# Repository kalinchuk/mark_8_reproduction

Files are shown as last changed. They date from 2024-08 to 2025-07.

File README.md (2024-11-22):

# Mark-8 Minicomputer Reproduction

This repository contains schematics, PCBs, instructions and parts lists for the Mark-8 minicomputer reproduction build which can be found at [https://www.youtube.com/watch?v=wndWWRKyKPk](https://www.youtube.com/watch?v=wndWWRKyKPk). The instructions and parts for most of the boards can be found at [https://bytecollector.com/archive/mark_8/My_Mark-8_Info/Mark-8_Construction/RE_Mark-8_Const-NEW.pdf](https://bytecollector.com/archive/mark_8/My_Mark-8_Info/Mark-8_Construction/RE_Mark-8_Const-NEW.pdf)

You can find the transcript of the interview with Jon Titus [here](/jon_titus_interview.txt).

## PCBs

Original Mark-8 PCBs are very rare. Therefore, if one has the desire to build a Mark-8, they need to use reproduction PCBs. I created reproduction PCBs from the layouts found in the construction manual and got a fabricater to fabricate a large quantity of them at a discount. If you're interested in a set, check out the [listing on www.kalinchuk.com](https://www.kalinchuk.com/product-page/mark-8-minicomputer-reproduction-pcb-set).

Mark-8 Reproduction PCBs

You can also fabricate the PCBs yourself by using the Gerber files under the [gerbers](/gerbers) directory.

## Note on Parts

- Any 74XX IC can be substituted with a 54XX (military grade) or, potentially, with a 74LSXX (Low-power Schottky).
- The Molex connectors that I used are the following:
  * 11-pin: https://www.mouser.com/ProductDetail/Molex/09-48-1114?qs=cSZs%252ByTnFTTJe86rNzFWuA%3D%3D
  * 10-pin: https://www.mouser.com/ProductDetail/Molex/09-48-1104?qs=DcEdecHHM4iSJPtLNet8eg%3D%3D
  * 8-pin: https://www.lvelectronics.com/details/item?itemid=MOLEX%2009-52-3081#
  * 6-pin: https://www.mouser.com/ProductDetail/Molex/09-48-1064?qs=qDyi%252BDzW2VMso3J1Nf5Bpg%3D%3D
  * 5-pin: https://www.mouser.com/ProductDetail/Molex/09-48-1054?qs=naUSJSqnqcLTt2tOKFjpcA%3D%3D
  * 2-pin: https://www.mouser.com/ProductDetail/Molex/09-48-1024?qs=SeTnVz%252B%252BFGB4BpEsDXmhhw%3D%3D
  * 1-pin: TBD

## LED Register Display Board

The LED Register Display board is used for displaying the address and contents of memory and output ports. It consists of 32 LEDs (8 for the high address, 8 for the low address, 8 for the address data and 8 for the output data).

### Parts List

| Part | Spec | Part # |
| --- | --- | --- |
| C1 | 100 uF | Sprague TE1211 |
| C2-C4 | 0.1 uF | ST/CO .1uf 25V ceramic disc |
| D1-D32 | 40mA LED | Western Electric LED; Original used Monsanto MV-50 but are very rare |
| R1-R32 | 220 ohm; 1/4W | Any carbon composition resistor |
| IC1-IC6 | 7404 | 5404J |
| IC7-IC8 | 7475 | 7475J |
| IC9 | 7442 | 7442J |
| IC10 | 7402 | 7402J |
| P1 | 3.96mm 8-pin| Molex 09-52-3081 |
| 41-PIN | 3.96mm 41-pin | MOLEX 09-48-1104 (x3) MOLEX 09-48-1114 (x1) |

### PCB

Mark-8 LED Register Display Board

## Output Ports Board

The output board is used for outputting data from the computer. It's a fairly simple board mostly consisting of ICs.

### Jumpers

There is one jumper in the middle of the board that needs to be installed. The additional jumpers will need to be installed according to the needs. For example, "A" can be jumpered with "1" to make CPU port 1 be output port A on the specific board. This allows for a maximum of 7 output ports with two output port boards.

Output Ports Jumpers

### Parts List

| Part | Spec | Part # |
| --- | --- | --- |
| C1-C3 | 0.1 uF | ST/CO .1uf 25V ceramic disc |
| IC1-IC8 | 7475 | 7475J |
| IC9-IC10 | 7404 | 7404J |
| IC11 | 7402 | 7402J |
| IC12 | 7442 | 7442J |
| P1-P4 | 3.96mm 8-pin| Molex 09-52-3081 |
| 41-PIN | 3.96mm 41-pin | MOLEX 09-48-1104 (x3) MOLEX 09-48-1114 (x1) |

### Test Circuit

The test circuit was taken from the Mark-8 Construction Manual Experiments section.

Output Ports Board Test Circuit

The following code will output 10101010 to output port 1 (remember that output port 0 is on the LED register display).

```
LDAI    AA       ;006 252
OUT1             ;123
HLT              ;777
```

### PCB

Output Ports Board

## Memory Board

The memory board accepts 32-1101 SRAM ICs but requires a minimum of 8 of them. Multiple memory boards can be installed into the Mark-8 computer and linked together.

### Bugs

Ensure that the 8 holes at the top of the board (going to the top connector) are not connected to GND with vias. Early versions of the reproduction PCBs will require those 8 holes to be drilled out.

### Jumpers

There is one jumper between IC33 and IC34. If this memory board is the first (and only) memory board to be installed, jumper the "0" position and the "A" positions. Additionally, select the correct memory block with the jumper positions above IC33. First memory board needs to jumper "0" to "A", "1" to "B", "2" to "C" and "3" to "D". If installing additional memory boards into the Mark-8, the jumpers would be different. Refer to page 6 of the Mark-8 construction manual for more details.

Memory Board Jumpers

### Parts List

| Part | Spec | Part # |
| --- | --- | --- |
| C1-C3 | 0.1 uF | ST/CO .1uf 25V ceramic disc |
| IC1-IC8 | 1101A or 1101A1 | 1101A |
| IC9-IC32 | 1101A or 1101A1 | *Optional |
| IC33 | 7442 | 7442J |
| IC34 | 7400 | 5400J |
| *R1-R11, R20-R21 | 1k ohm; 1/4W | Any carbon composition resistor |
| *R12-R19 | 10k ohm; 1/4W | Any carbon composition resistor |
| P1 | 3.96mm 8-pin| Molex 09-52-3081 |
| P2 | 3.96mm 2-pin| Molex 09-48-1024 |
| 41-PIN | 3.96mm 41-pin | MOLEX 09-48-1104 (x3) MOLEX 09-48-1114 (x1) |

* For the first memory board, install all resistors. If installing additional memory boards, some resistors are omitted. Refer to page 6 of the Mark-8 construction manual for more details.

### Test Program

The following code will output 10101010 to output port 0 (LED register display) to test the functionality of the memory board.

```
LDAI    AA       ;006 252
OUT0             ;121
HLT              ;777
```

### PCB

Memory Board

## Address Latch Board

The address latch board latches addresses specified by the end-user which are then relayed to the memory board.

### Bugs

In addition to the bugs specified on the official bugs sheet, IC8-IC11 pin 4 needs to be pulled up to +5v with a 1k ohm pull-resistor (ref: https://www.ti.com/lit/ds/symlink/sn54ls193-sp.pdf).

Address Latch Board Pull-Up Resistors

Early versions of the reproduction PCBs also have an additional bug - one of the vias is missing and needs to be drilled out and connected with a piece of wire.

Address Latch Board Bug

### Jumpers

There are two jumpers that need to be installed. The larger jumper is not annotated on the parts layout sheet but the holes do exist for it.

Address Latch Board Jumpers

### Parts List

| Part | Spec | Part # |
| --- | --- | --- |
| C1-C6 | *0.1 uF | ST/CO .1uf 25V ceramic disc |
| C7 | 680 pF | RMC 680pf 100V ceramic disc |
| IC1-IC2 | 74123 | 74123J |
| IC3-IC7 | 7400 | 5400J |
| IC8-IC11 | 74193 | 74193J |
| R1-R3 | 10k ohm; 1/4W | Any carbon composition resistor |
| R4 | 22k ohm; 1/4W | Any carbon composition resistor |
| R5-R16 | 1k ohm; 1/4W | Any carbon composition resistor |
| P1 | 3.96mm 8-pin| Molex 09-52-3081 |
| P2 | 3.96mm 5-pin| Molex 09-48-1054 |
| P2 | 3.96mm 6-pin| Molex 09-48-1064 |
| 41-PIN | 3.96mm 41-pin | MOLEX 09-48-1104 (x3) MOLEX 09-48-1114 (x1) |

* The original parts list calls for 0.01 uF but that may be a mistake so I decided to use 0.1 uF instead.

### PCB

Address Latch Board

## Input Multiplex Board

The input multiplex board controls all data flowing into the computer and data between memory and CPU.

### Bugs

In addition to the bugs specified on the official bugs sheet, older versions of this board had two fabrication issues.

The jumper on the right side is missing a hole. This is because the other side of the board does not have a pad. This can be fixed by drilling out a hole using a [#60 (1mm) drill bit](https://amzn.to/3Vpg0OW) and [chuck](https://amzn.to/3VcrNii). Alternatively, a jumper wire can be soldered directly onto the trace.

Input Multiplex Board Bug 1

IC1 has one of the pins connected to a passing trace. This is a frabrication issue and can be fixed by cutting the connection with a utility knife or small grinder (carefully).

Input Multiplex Board Bug 2

### Jumpers

There are two official jumpers and one additional jumper which was noted on the bugs sheet.

Input Multiplex Board Jumpers

### Parts List

| Part | Spec | Part # |
| --- | --- | --- |
| C1, C3-C4  | 0.1 uF | ST/CO .1uf 25V ceramic disc |
| C2 | 100 uF | Sprague TE1211 |
| IC1-IC2 | 8263 MUX | N8263N - can be found on eBay |
| IC3 | 7400 | 7400J |
| IC4-IC5 | 8267 MUX | N8267B - can be found on eBay. Do not use 8266 |
| IC6 | 7402 | 7402J |
| IC7 | 7442 | 7442J |
| R1 | 1k ohm; 1/4W | Any carbon composition resistor |
| P1-P4 | 3.96mm 8-pin| Molex 09-52-3081 |
| 41-PIN | 3.96mm 41-pin | MOLEX 09-48-1104 (x3) MOLEX 09-48-1114 (x1) |

### PCB

Input Multiplex Board

## CPU Board

The CPU board contains the 8008 microprocessor and is the "brain" of the computer.

### Bugs

The bugs sheet on page 46 states that IC3 pin 4 can be connected to ground. Some boards may have experienced issues with the pin not being grounded.

### Jumpers

The board has two official jumpers as annotated on the parts layout sheet.

CPU Board Jumpers

As mentioned in the Bugs section, I went ahead and connected IC3 pin 4 to ground by soldering it to the passing trace (since that trace is connected to ground).

CPU Board Bug

### Parts List

| Part | Spec | Part # |
| --- | --- | --- |
| C1 | 33 pF | RMC 3000V 33pF 10% ceramic disc |
| C2-C6 | 0.1 uF | ST/CO .1uf 25V ceramic disc |
| IC1, IC4, IC6-IC7, IC9, IC13, IC17, IC19 | 7400 | 5400J |
| IC2-IC3, IC14 | 7476 | 5476J |
| IC5, IC11, IC16, IC20, IC21 | 7404 | 5404J |
| IC8, IC12 | 7474 | 5474J |
| IC22-IC23, IC25 | 74L04 | 74L04 |
| IC10, IC18 | 7410 | 7410J |
| IC15 | 7420 | 7420J |
| IC24 | Intel 8008 | Intel C8008 |
| IC26 | 7442 | 7442J |
| R1-R2 | 220 ohm; 1/4W | Any carbon composition resistor |
| R3 | 560 ohm; 1/4W | Any carbon composition resistor |
| R4 | 1.8k ohm; 1/4W | Any carbon composition resistor |
| R5-R8, R17 | 1k ohm; 1/4W | Any carbon composition resistor |
| R9-R16 | 22k ohm; 1/4W | Any carbon composition resistor |
| XTAL 1 | 4.0 MHz | 4.0 MHz Crystal |
| 41-PIN | 3.96mm 41-pin | MOLEX 09-48-1104 (x3) MOLEX 09-48-1114 (x1) |

### PCB

CPU Board

## Backplane

The backplane is used for connecting all the boards together. The original Mark-8 did not have a backplane so all boards had to be manually connected with wires.

### Parts List

| Part | Spec | Part # |
| --- | --- | --- |
| 41-PIN | 3.96mm 41-pin | 	11-position (TE Connectivity AMP Connectors 1-640383-1) & 10-position (TE Connectivity AMP Connectors 1-640383-0) |
| Power Connector | BARRIER STRIP 3CIRC | Amphenol Anytek YK3030323000G |

### PCB

Backplane

## Power Supply

The original Mark-8 minicomputer did not come with a power supply but did suggest a specific power supply of +5 volts (3 amps) and -9 volts (1.5 amps). The following is a linear power supply consistent with how power supplies in the 1970s were made.

You can purchase an unstuffed PCB at [www.kalinchuk.com](https://www.kalinchuk.com/product-page/mark-8-minicomputer-power-supply-pcb)

### Schematic & Gerber

You will find the V1 schematic and Gerber below.

Power Supply Schematic

You can also download a [high quality PDF](https://github.com/user-attachments/files/16600388/Schematic.pdf).

If you would like to fabricate the PCB yourself, the [V1 Gerber](https://github.com/user-attachments/files/16600408/GerberV1.zip) is available for download.

### Parts List

| Part | Spec | Part # |
| --- | --- | --- |
| D1-D4 |	1N5408 | Digikey 641-1316-1-ND |
| D5-D6 | 5mm	LED | Any LED |
| C1-C2	 | 4,700 uF 35V | Digikey P15166-ND |
| C3-C4, C8-C9 | 	0.1 uF | ST/CO .1uf 25V ceramic disc |
| C5, C10 |	10 uF | Illinois Capacitor 106RAR035A |
| C6-C7 |	2,200 uF 35V | Digikey 1189-2266-ND |
| J1-J2	 | 3.96mm 3-pos | Digikey YK3030323000G-ND |
| R1	 | 820 ohm | Any carbon composition resistor |
| R2	 | 270 ohm | Any carbon composition resistor |
| R3	 | 220 ohm | Any carbon composition resistor |
| R4	 | 1.5k ohm | Any carbon composition resistor |
| R5	 | 230 ohm | Any carbon composition resistor |
| R6	 | 330 ohm | Any carbon composition resistor |
| U1	 | LM338 | Digikey LM338T/NOPB-ND |
| U2	 | LM337 | Digikey LM337TNS/NOPB-ND |
| U1 Heat Sink	| 2.00°C/W or less  | Digikey 6400BG-ND |
| U2 Heat Sink	| 10.00°C/W or less | Digikey 6400BG-ND |

### Parts Layout

Download the [Parts Layout PDF](https://github.com/user-attachments/files/16593340/Parts.Layout.V1.pdf)

### Notes

It's important to use a correctly sized heat sink for each voltage regulator otherwise they will burn out. The 5 volt regulator (U1) needs a heat sink with thermal resistance of 2.00°C/W or less. The -9 volt regulator (U2) needs a heat sink with thermal resistance of 10.00°C/W or less.

### PCB

Power Supply

## Front Panel

The front panel has 16 switches and an opening for the lights. You can find the parts used to build the front panel, below. You can also find the blank panel for sale at [www.kalinchuk.com](https://www.kalinchuk.com/product-page/mark-8-reproduction-front-panel).

### Parts List

| Part | Spec | Part # |
| --- | --- | --- |
| SPDT Switch | x10 | [M2012TJW02-GA-1A](https://www.powell.com/powell/en/USD/Products/Electromechanical/Switches/p/M2012TJW02-GA-1A/NKK-Switches/000000001000260706)  |
| SPDT Momentary Switch | x6 | [M2015TJW01-GA-1A](https://www.digikey.com/en/products/detail/nkk-switches/M2015TJW01-GA-1A/1165800) |
| Plexiglass | ~5" x 6" | 1/8" thick [amazon](https://www.amazon.com/gp/product/B0CLNH69B8) |
| 14 gauge wire | n/a | n/a |
| 20 guage wire | n/a | n/a |
| Shrink tubing | n/a | n/a |
| Crimp pins | 18-24 guage pin | [0002062103](https://www.digikey.com/en/products/detail/molex/0002062103/26253) |
| Aqua satin paint | n/a | n/a |

### Image

Inside the case:

Inside the case

Front of the case:

Front of the case

## Case

The original Mark-8 did not come with a case nor did it specify a recommended case. The case we will be building is a close replica of the one shown on the front page of the July 1974 Radio Electronics magazine.

July 1974 Radio Electronics Case

It's made out of 100% aluminum frame and panels. All panels are 1/16" thick. The aluminum frame members are 1" x 1". All this metal adds quite a bit of weight to the case but it's very solid.

### Drawings

Below, you will find the rough drawings that were drawn up before the CAD files were created.

*Vertical Member*

Case Vertical Member

[Full PDF](https://github.com/user-attachments/files/16801457/VerticalPiece.pdf)

*Horizontal Member*

Case Horizontal Member

There are two sizes of the horizontal member - 15-1/4" and 9"
[Full PDF](https://github.com/user-attachments/files/16801461/HorizontalPiece.pdf)

*Front Panel*

Case Front Panel

[Full PDF](https://github.com/user-attachments/files/16801467/Scan2024-08-01_135943.pdf)

*Rear Panel*

Case Rear Panel

The first version of the rear panel has a fan cut-out and also ports for the power plug and switch.
[Full PDF](https://github.com/user-attachments/files/16801468/Scan2024-08-04_144435.pdf)

### CAD Files

[Vertical Member IGES](case/3D_Vertical_Piece.iges)

[Horizontal Member 9" IGES](case/3D_Horizonal_Piece_9.iges)

[Horizontal Member 15-1/4" IGES](case/3D_Horizonal_Piece_15-1_4.iges)

[Front Panel IGES](case/Cutout_Sheet_Rev_1.iges)

[Rear Panel V1 IGES](case/2D_Sheetmetal_Fan_Grill.iges)

### Fabrication Notes

The vertical members are CNC machined aluminum. Four are required for the case. It contains four threads per piece so be sure to select "threads" when ordering from a CNC service (such as PCBWay).

The horizontal members are also CNC machined aluminum and contain threads (select "threads" when ordering). There are two sizes of the horizontal members - one is 15-1/4" long and the other is 9" long. The case requires four of each size.

The front panel is 1/16" thick aluminum sheet metal. I spray painted mine with aqua (satin) paint.

The rear panel is 1/16" thick aluminum sheet metal. Version 1 contains an opening for a fan, power plug and switch. Version 2 is also contains openings for serial ports.

When ordering, make sure to select "CNC" for vertical and horizontal pieces and "sheet metal" for all others.

The remaining sides of the enclosure are standard 1/16" thick aluminum sheets cut to size. I use OnlineMetals.com for this.
* Side pieces are 10.0"x8.75", 1/16" thick (2)
* Top piece is 17.25"x11.0", 1/16" thick (1)
* Bottom piece is also 17.25"x11.0" but 1/8" thick (1)

To assemble the case, 48 #10-24 x 3/8" screws will be required.

### Additional Notes

The Mark-8 will fit quite well into the case but, due to the size of the frame members, the front panel lights will not line up exactly with the opening of the front panel. I think the front panel design will be modified in the future so that the opening is moved slightly left.

Case Front Panel Opening

The power supply fights perfectly to the left of the Mark-8 computer. Additional pieces (i.e. power transformer, barrier strip, etc.) will fit in the remaining space. I also added a fan to the left of the power supply to cool it down since it gets quite hot.

Case From Top

### Parts List

| Part | Spec | Part # |
| --- | --- | --- |
| Rubber Feet |	Any size | [Amazon](https://amzn.to/4cNOoIW) |
| Barrier Strip | 110-220V 3A Min - 2/3 position | [Amazon](https://amzn.to/3T9KWRE) |
| Power Transformer | 3A Center Tap 12V-0-12V 24VAC | [eBay](https://www.ebay.com/itm/124225528946) |
| Power Plug | Standard size | [DigiKey](https://www.digikey.com/en/products/detail/schurter-inc/6162-0159/2646985) |

### Final

Case Final

## Original Case

The construction manual did not recommend a case for the Mark-8 minicomputer but the case that was used for the Mark-8 that was featured on the front cover of the Radio Electronics magazine was made by Bud Industries and had a part number of SB-2142. Those cases are still available for sale from various sources. The one I purchased was from https://www.testequity.com/product/10014392-SB-2142

### CAD Files

These CAD files are for the Bud Industries case. I have not tested them, personally, but the dimensions should be correct.

[Front Panel](case/Bud%20Industries%20Case/FrontPanel.iges)

[Rear Panel](case/Bud%20Industries%20Case/RearPanel.iges)

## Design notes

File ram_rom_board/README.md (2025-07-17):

# Mark-8 16K RAM/ROM Board

This RAM/ROM board for the Mark-8 minicomputer was designed by Len Bayles who, kindly, shared the Gerber file and documentation with me and helped me get familiar with it. Be sure to check out his website at [https://www.chronworks.com/](https://www.chronworks.com/).

This board will work with any reproduction Mark-8 minicomputer that uses a backplane with a 3.96mm pitch.

## PCB

PCBs are available for sale at [kalinchuk.com](https://www.kalinchuk.com/product-page/mark-8-minicomputer-rom-board)



## Gerber

You can find the Gerber file under the "Gerber" directory. Be sure to credit Len Bayles if sharing publicly.

## Parts

The following parts list contains a suggested part number for each part but any comparable part will do.

Additionally, the board can be configured for RAM or ROM (or both). If using as RAM only, populate the SRAMs and leave the EPROMs out. If using as ROM only, populate the EPROMs and leave the SRAMs out. If using both RAM and ROM, populate both the EPROMs and the SRAMs.

| Part | Spec | Quantity | Part # |
| --- | --- | ---| --- |
| C1 | 47 uF, 25v, axial elec.  | 1 | [Cornell Dubilier Knowles #476TTA025M](https://www.digikey.com/en/products/detail/cornell-dubilier-knowles/476TTA025M/5412827) |
| C2-C14 | 0.1 uF ceramic | 13 | [KEMET #C320C104K5R5TA](https://www.digikey.com/en/products/detail/kemet/C320C104K5R5TA/818040) |
| C15 | 22 uF, 25v, axial elec.  | 1 | [Cornell Dubilier Knowles #226BPA025M](https://www.digikey.com/en/products/detail/cornell-dubilier-knowles/226BPA025M/5411600) |
| D1-D4 | 1n914 | 4 | [onsemi #1N914](https://www.digikey.com/en/products/detail/onsemi/1N914/978749) |
| D5-D6 | 5mm LED | 2 | [Kingbright #WP7113ID](https://www.digikey.com/en/products/detail/kingbright/WP7113ID/1747663) |
| J1 | 41-pos Molex (3.96mm) | 3x10-pos, 1x11-pos | [Molex #09-48-1104](https://www.digikey.com/en/products/detail/molex/0009481104/863329) & [Molex #09-48-1114](https://www.digikey.com/en/products/detail/molex/0009481114/863330) |
| J2, J4 | 8-pos Molex (3.96mm) | 2 | [Molex #09-48-1084](https://www.digikey.com/en/products/detail/molex/0009481084/863327) |
| J3 | 2-pos Molex (3.96mm) | 1 | [Molex #09-48-1024](https://www.digikey.com/en/products/detail/molex/0009481024/863321) |
| R1-R2, R4  | 1k 1/4w | 3 | [Stackpole Electronics Inc #CF14JT1K00](https://www.digikey.com/en/products/detail/stackpole-electronics-inc/CF14JT1K00/1741314) |
| R3 | 4.7k 1/4w | 1 | [Stackpole Electronics Inc #CF14JT4K70](https://www.digikey.com/en/products/detail/stackpole-electronics-inc/CF14JT4K70/1741428) |
| RN1-RN3 | 10k x 8 | 3 | [Bourns Inc. #4609M-101-103LF](https://www.digikey.com/en/products/detail/bourns-inc/4609M-101-103LF/3787785) |
| RN4 | 1k x 8 | 1 | [Bourns Inc. #4609M-101-102LF](https://www.digikey.com/en/products/detail/bourns-inc/4609M-101-102LF/3787784) |
| SW1-SW2 | DIP switch x 8 | 2 | [CTS Electrocomponents #195-8MST](https://www.digikey.com/en/products/detail/cts-electrocomponents/195-8MST/90523) |
| SW3 | Tactile switch | 1 | [TE Connectivity ALCOSWITCH Switches #1825910-6](https://www.digikey.com/en/products/detail/te-connectivity-alcoswitch-switches/1825910-6/1632536) |
| U1-U2 | 74LS244 | 2 | [Texas Instruments #SN74LS244N](https://www.digikey.com/en/products/detail/texas-instruments/SN74LS244N/277299) |
| U3 | 74LS00 | 1 | [Texas Instruments #SN74LS00N](https://www.digikey.com/en/products/detail/texas-instruments/SN74LS00N/277272) |
| U4, U20 | 74LS02 | 2 | [Texas Instruments #SN74LS02N](https://www.digikey.com/en/products/detail/texas-instruments/SN74LS02N/277273) |
| U5-U8 | 74LS85 | 4 | [Texas Instruments #SN74LS85N](https://www.digikey.com/en/products/detail/texas-instruments/SN74LS85N/563035) |
| U9-U10 | 2716 EPROM | 2 | [Major Brands #D2716](https://www.jameco.com/z/D2716-Major-Brands-IC-2716-EPROM-16K-Bit-450ns-NMOS-UV-Erasable-and-Electrically-Programmable-EPROM_40002.html) |
| U11-U18 | AM2167 SRAM  | 8 | [Advanced Micro Devices, Inc. #AM2167-45PC](https://specialtypartsinc.com/products/1-pc-am2167-45pc-amd-standard-sram-16kx1-40ns-nmos-pdip20) |
| U19 | 74LS30 | 1 | [Texas Instruments #SN74LS30N](https://www.digikey.com/en/products/detail/texas-instruments/SN74LS30N/377726) |
| U21-U22 | 74LS175 | 2 | [Texas Instruments #SN74LS175N](https://www.digikey.com/en/products/detail/texas-instruments/SN74LS175N/277294) |
| The following are optional but recommended: |
| 14 pin socket  | 14-pin | 4 | [CNC Tech #245-14-1-03](https://www.digikey.com/en/products/detail/cnc-tech/245-14-1-03/3441580) |
| 16 pin socket  | 16-pin | 6 | [CNC Tech #245-16-1-03](https://www.digikey.com/en/products/detail/cnc-tech/245-16-1-03/3441581) |
| 20 pin socket  | 20-pin | 10 | [CNC Tech #245-20-1-03](https://www.digikey.com/en/products/detail/cnc-tech/245-20-1-03/3441583) |
| 24 pin socket  | 24-pin | 2 | [CNC Tech #245-24-1-06](https://www.digikey.com/en/products/detail/cnc-tech/245-24-1-06/3441585) |

## Parts Placement & Schematics

The PCB may not contain a silk screen with all the parts outlined. If that's the case for you, refer to the [Parts Placement PDF](PartsPlacement.pdf). Additionally, the schematics are provided under the "Schematics" directory.

## Configuration

The ROM board is configured using the two DIP switches at the top of the board, one for each PROM. The left DIP switch configures the left PROM and the right DIP switch configures the right PROM. If you are not using any of the PROMs, disable them by "turning on" the right two switches (DIS ROM MAN, DIS ROM IO). Conversely, if you want to enable a PROM, switch the "DIS ROM MAN" switch to the "off" position. The switches are basically backwards (on is off and off is on).

Switches

The remaining switches are used to configure the base and block. A variety of different configurations can be used, depending on the needs. For example, to enable the ROM at 8K memory space, "turn on" switches 4-8.

## Programming PROMs

The board supports 2716 EPROMs. These EPROMs can be programmed in a variety of ways but I've been using the [XGecu T48](https://www.amazon.com/dp/B0B592HZ1K) programmer and it has worked very well for me.

You will need a binary file to program the EPROM. Either use one of the binary files located under the "software" directory or create one yourself. To assemble an ASM file, I used the [Retro Assembler](https://enginedesigns.net/retroassembler) which works on Windows and Mac.

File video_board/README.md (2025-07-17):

# Mark-8 Video Board

This video board for the Mark-8 minicomputer was designed by Len Bayles who, kindly, shared the Gerber file and documentation with me and helped me get familiar with it. Be sure to check out his website at [https://www.chronworks.com/](https://www.chronworks.com/).

This board will work with any reproduction Mark-8 minicomputer that uses a backplane with a 3.96mm pitch.

## PCB

PCBs are available for sale at [www.kalinchuk.com](https://www.kalinchuk.com/product-page/mark-8-minicomputer-video-board)

Mark-8 Video Board PCB

## Gerber

You can find the Gerber file under the [Gerber](Gerber) directory. Be sure to credit Len Bayles if sharing publicly.

## Parts

The following parts list contains a suggested part number for each part but any comparable part will do.

The 2716 EPROM is used as a character generator and needs to be programmed with [charGen.hex](Software/charGen.hex).

| Part | Spec | Quantity | Part # |
| --- | --- | ---| --- |
| C1, C10 | 0.01 uF ceramic  | 2 | [Vishay Beyschlag #D103Z25Z5VF63L6R](https://www.digikey.com/en/products/detail/vishay-beyschlag-draloric-bc-components/D103Z25Z5VF63L6R/2832593) |
| C2 | 50 pF trimmer | 1 | [Jameco ValuePro #CTC05-50](https://www.jameco.com/webapp/wcs/stores/servlet/ProductDisplay?productId=136979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) |
| C3 | 220 pF ceramic | 1 | [Vishay Beyschlag #D221K20Y5PH63L6R](https://www.digikey.com/en/products/detail/vishay-beyschlag-draloric-bc-components/D221K20Y5PH63L6R/769380) |
| C4 | 4.7 uF, 25v, axial elec.  | 1 | [Vishay Beyschlag #MAL202128478E3](https://www.digikey.com/en/products/detail/vishay-beyschlag-draloric-bc-components/MAL202128478E3/5632105) |
| C5 | 1000 pF ceramic  | 1 | [Vishay Beyschlag #D102K25Y5PL63L6R](https://www.digikey.com/en/products/detail/vishay-beyschlag-draloric-bc-components/D102K25Y5PL63L6R/769395) |
| C6, C101-C106, C201-C206, C301-C306, C401-C406 | 0.1 uF ceramic | 25 | [KEMET #C320C104K5R5TA](https://www.digikey.com/en/products/detail/kemet/C320C104K5R5TA/818040) |
| C7 | 100 pF ceramic | 1 | [Vishay Beyschlag #MAL202137101E3](https://www.digikey.com/en/products/detail/vishay-beyschlag-draloric-bc-components/MAL202137101E3/262952) |
| C8 | 0.05 uF ceramic  | 1 | [Vishay Beyschlag/Draloric/BC Components #S503Z69Z5UL63L0R](https://www.digikey.com/en/products/detail/vishay-beyschlag-draloric-bc-components/S503Z69Z5UL63L0R/2832563) |
| C9 | 10 uF, 25v, radial elec.  | 1 | [Vishay Beyschlag #MAL214258109E3](https://www.digikey.com/en/products/detail/vishay-beyschlag-draloric-bc-components/MAL214258109E3/2691024) |
| J1 | 41-pos Molex (3.96mm) | 3x10-pos, 1x11-pos | [Molex #09-48-1104](https://www.digikey.com/en/products/detail/molex/0009481104/863329) & [Molex #09-48-1114](https://www.digikey.com/en/products/detail/molex/0009481114/863330) |
| J2 | RCA jack | 1 | [Same Sky #RCJ-014](https://www.digikey.com/en/products/detail/same-sky-formerly-cui-devices/RCJ-014/408490) |
| L1 | 6.8 uH axial | 1 | [Bourns Inc. #8250-682K-RC](https://www.digikey.com/en/products/detail/bourns-inc/8250-682K-RC/4697666) |
| PS1 | DC-DC CONVERTER +5V to +/-12V 2W | 1 | [CUI Inc. #PDM2-S5-D12-S](https://www.digikey.com/en/products/detail/cui-inc/PDM2-S5-D12-S/4009656) |
| Q1-Q2 | 2n2222 | 2 | [STMicroelectronics #2N2222](https://www.digikey.com/en/products/detail/stmicroelectronics/2N2222/654412) |
| R1-R2 | 330 1/4w | 2 | [Stackpole Electronics Inc #CF14JT330R](https://www.digikey.com/en/products/detail/stackpole-electronics-inc/CF14JT330R/1741399) |
| R3 | 8.2k 1/4w  | 1 | [Stackpole Electronics Inc #CF14JT8K20](https://www.digikey.com/en/products/detail/stackpole-electronics-inc/CF14JT8K20/1741509) |
| R4, R6 | 50k pot | 2 | [Bourns Inc. #PV36W503C01B00](https://www.digikey.com/en/products/detail/bourns-inc/PV36W503C01B00/666516) |
| R5, R15 | 22k 1/4w | 2 | [Stackpole Electronics Inc #CF14JT22K0](https://www.digikey.com/en/products/detail/stackpole-electronics-inc/CF14JT22K0/1741350) |
| R7, R12-R13| 5.1k 1/4w  | 3 | [Stackpole Electronics Inc #CF14JT5K10](https://www.digikey.com/en/products/detail/stackpole-electronics-inc/CF14JT5K10/1741447) |
| R8, R101(4) | 1k 1/4w | 5 | [Stackpole Electronics Inc #CF14JT1K00](https://www.digikey.com/en/products/detail/stackpole-electronics-inc/CF14JT1K00/1741314) |
| R9 | 2.2k 1/4w  | 1 | [Stackpole Electronics Inc #CF14JT2K20](https://www.digikey.com/en/products/detail/stackpole-electronics-inc/CF14JT2K20/1741321) |
| R10 | 56 1/4w | 1 | [Stackpole Electronics Inc #CF14JT56R0](https://www.digikey.com/en/products/detail/stackpole-electronics-inc/CF14JT56R0/1741465) |
| R11 | 68 1/4w | 1 | [Stackpole Electronics Inc #CF14JT68R0](https://www.digikey.com/en/products/detail/stackpole-electronics-inc/CF14JT68R0/1741487) |
| R14 | 3.9k 1/4w  | 1 | [Stackpole Electronics Inc #CF14JT3K90](https://www.digikey.com/en/products/detail/stackpole-electronics-inc/CF14JT3K90/1741386) |
| U1, U16, U41 | 7404 | 4 | [Texas Instruments #SN7404N](https://www.digikey.com/en/products/detail/texas-instruments/SN7404N/555980) |
| U2 | 74LS76 | 1 | [Texas Instruments #SN74LS112AN](https://www.digikey.com/en/products/detail/rochester-electronics-llc/SN74LS112AN/13528151) |
| U3 | 7490 | 1 | [onsemi #DM7490AN](https://www.digikey.com/en/products/detail/onsemi/DM7490AN/3144) |
| U4 | 7400 | 1 | [Texas Instruments #SN7400N](https://www.digikey.com/en/products/detail/texas-instruments/SN7400N/555975) |
| U5 | MM5321 (sync gen) | 1 | [National Semiconductor #MM5321N](https://www.ebay.com/itm/165651436117) |
| U6, U39 | 7410 | 2 | [onsemi #SN7410N](https://www.digikey.com/en/products/detail/texas-instruments/SN7410N/11519655) |
| U7-U9, U11-U12, U18-U20 | 74LS193 | 9 | [Texas Instruments #SN74LS193N](https://www.digikey.com/en/products/detail/texas-instruments/SN74LS193N/277295) |
| U10 | 74LS00 | 1 | [Texas Instruments #SN74LS00N](https://www.digikey.com/en/products/detail/texas-instruments/SN74LS00N/277272) |
| U14 | 2716 EPROM (char gen) | 1 | [Major Brands #D2716](https://www.jameco.com/z/D2716-Major-Brands-IC-2716-EPROM-16K-Bit-450ns-NMOS-UV-Erasable-and-Electrically-Programmable-EPROM_40002.html) |
| U15 | 74165 | 1 | [Texas Instruments #SN74LS165AN](https://www.digikey.com/en/products/detail/texas-instruments/SN74LS165AN/563051) |
| U17 | 74LS30 | 1 | [Texas Instruments #SN74LS30N](https://www.digikey.com/en/products/detail/texas-instruments/SN74LS30N/377726) |
| U21 | 74LS32 | 1 | [Texas Instruments #SN74LS32N](https://www.digikey.com/en/products/detail/texas-instruments/SN74LS32N/277304) |
| U22 | 74LS138 | 1 | [Texas Instruments #SN74LS138N](https://www.digikey.com/en/products/detail/texas-instruments/SN74LS138N/277285) |
| U23 | 74LS244 | 1 | [Texas Instruments #SN74LS244N](https://www.digikey.com/en/products/detail/texas-instruments/SN74LS244N/277299) |
| U24-U26 | 74LS157 | 3 | [Texas Instruments #SN74LS157N](https://www.digikey.com/en/products/detail/texas-instruments/SN74LS157N/277291) |
| U27-U33 | 2102 SRAM  | 7 | [National Semiconductor #MM2102AN-4](https://www.jameco.com/z/MM2102AN-4-National-Semiconductor-IC-MM2102AN-4-NMOS-SRAM-1024-Bit-1024x1-250ns-DIP-16_2287991.html) |
| U34, U13 | 74LS123 | 1 | [Texas Instruments #SN74LS123N](https://www.digikey.com/en/products/detail/texas-instruments/SN74LS123N/277282) |
| U35-U37 | 74LS85 | 3 | [Texas Instruments #SN74LS85N](https://www.digikey.com/en/products/detail/texas-instruments/SN74LS85N/563035) |
| U38 | 74LS74 | 1 | [Texas Instruments #SN74LS74AN](https://www.digikey.com/en/products/detail/texas-instruments/SN74LS74AN/277314) |
| U40 | 555 timer  | 1 | [Texas Instruments #LM555CN/NOPB](https://www.digikey.com/en/products/detail/texas-instruments/LM555CN-NOPB/6575) |
| X1 | 14.31818 MHz | 1 | [Abracon LLC #AB-14.31818MHZ-B2](https://www.digikey.com/en/products/detail/abracon-llc/AB-14-31818MHZ-B2/675199) |
| The following are optional but recommended: |
| 8 pin socket  | 8-pin | 1 | [CNC Tech #243-08-1-03](https://www.digikey.com/en/products/detail/cnc-tech/243-08-1-03/3441568) |
| 14 pin socket  | 14-pin | 11 | [CNC Tech #245-14-1-03](https://www.digikey.com/en/products/detail/cnc-tech/245-14-1-03/3441580) |
| 16 pin socket  | 16-pin | 26 | [CNC Tech #245-16-1-03](https://www.digikey.com/en/products/detail/cnc-tech/245-16-1-03/3441581) |
| 20 pin socket  | 20-pin | 1 | [CNC Tech #245-20-1-03](https://www.digikey.com/en/products/detail/cnc-tech/245-20-1-03/3441583) |
| 24 pin socket  | 24-pin | 1 | [CNC Tech #245-24-1-06](https://www.digikey.com/en/products/detail/cnc-tech/245-24-1-06/3441585) |

## Parts Placement & Schematics

The PCB should contain the silk screen with the parts placement but, if it doesn't, refer to [Mark8_tvt_parts.pdf](Schematics/Mark8_tvt_parts.pdf) for the parts placement. Additionally, the schematics are provided under the "Schematics" directory.

## Configuration

### Character generator

Program a 2716 EPROM (used as a character generator) with the [charGen.hex](Software/charGen.hex) hex file. A programmer for this (and other) EPROMs can be found on [Amazon](https://www.amazon.com/ACEIRMC-TL866-3G-Programmer-Support-Replacement/dp/B0BFWKS53B).

### Video position

To adjust the video position (vertical and horizontal) adjust the resistors R4 and R6. I found that having C6 at 0.2 uF (instead of 0.1 uF) gives me more vertical adjustment room.

### Video quality

C2 can be adjusted, if desired, to improve image quality.

### Port configuration

At the bottom right corner of the board, you can find the positions DI (Data In), CA (Column Address) and RA (Row Address). Those positions can be jumpered to positions 0-7 on the right side to change the port numbers for data input, column address and row address (existing, default traces may need to be removed). The default ports are Data In (5), Column Address (6), Row Address (7).

## Bugs

Older versions of this board contained a few bugs that need to be repaired before operation. These bug were fixed in version B of the board.

1) Cut trace of U19 pin 1 and tie it to ground.



2) Cut trace between U22 pin 9 and CA. Run jumper between U22 option hole #3 and CA.



## Sample program

The following sample program will output characters on the screen at position 0,0.

```assembly
  ;
  ; tvt.asm
  ;
  ; Intel 8008 source code file.
  ;
  ; Copyright 2015 by Len Bayles
  ;

CHAR_OUT: equ 5
COL_OUT:  equ 6
ROW_OUT:  equ 7

  ; page 0

  cpu 8008

  org 000#000

main:
  lai 0x00
  out COL_OUT ; Put value on output port
  out ROW_OUT ; Put value on output port

  lai 0x48
  out CHAR_OUT  ; Put value on output port

  lai 0x69
  out CHAR_OUT  ; Put value on output port
  
  end
```

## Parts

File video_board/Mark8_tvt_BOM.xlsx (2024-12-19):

C1 | 0.01
C2 | 50pf trimmer | Jameco 136979
C3 | 220pf
C4 | 4.7uf | 4065PHCT-ND
C5 | 1000p
C6 | 0.1
C7 | 100
C8 | 0.05
C9 | 10uf
C10 | 0.01
L1 | 6.8uh
PS1 | DC CONV | 102-2732-nd
Q1 | 2N2222
Q2 | 2N2222
R1 | 330
R2 | 330
R3 | 8.2k
R4 | 50k
R5 | 22k
R6 | 50k
R7 | 5.1k
R8 | 1k
R9 | 2.2k
R10 | 56
R11 | 68
R12 | 5k
R13 | 5k
R14 | 3.9k
R15 | 22k
R101 | 1k
R102 | 1k
U1 | 7404
U1 | 74LS04
U2 | 74LS04
U2 | 74LS76
U3 | 7490
U4 | 7400
U5 | MM5321
U6 | 7410
U6 | 74LS10
U7 | 74LS193
U8 | 74LS193
U9 | 74LS193
U10 | 74LS00
U11 | 74LS193
U12 | 74LS193
U13 | 74LS123
U14 | 2716
U15 | 74165
U16 | 74LS04
U17 | 74LS30
U18 | 74LS193
U19 | 74LS193
U20 | 74LS193
U21 | 74LS32
U22 | 74LS138
U23 | 74LS244
U24 | 74LS157
U25 | 74LS157
U26 | 74LS157
U27 | 2102
U28 | 2102
U29 | 2102
U30 | 2102
U31 | 2102
U32 | 2102
U33 | 2102
U34 | 74LS123
U35 | 74LS85
U36 | 74LS85
U37 | 74LS85
U38 | 74LS74
U39 | 74LS10
U40 | 555
U41 | 74LS04
X1 | 14.31818

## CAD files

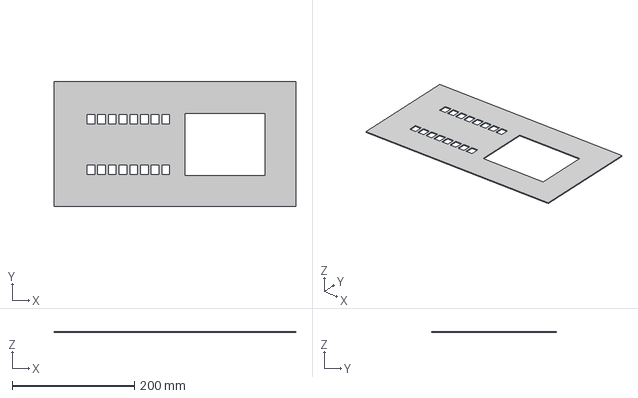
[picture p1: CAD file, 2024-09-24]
case/Bud Industries Case/FrontPanel.iges
395.3 x 204.8 x 1.59 mm

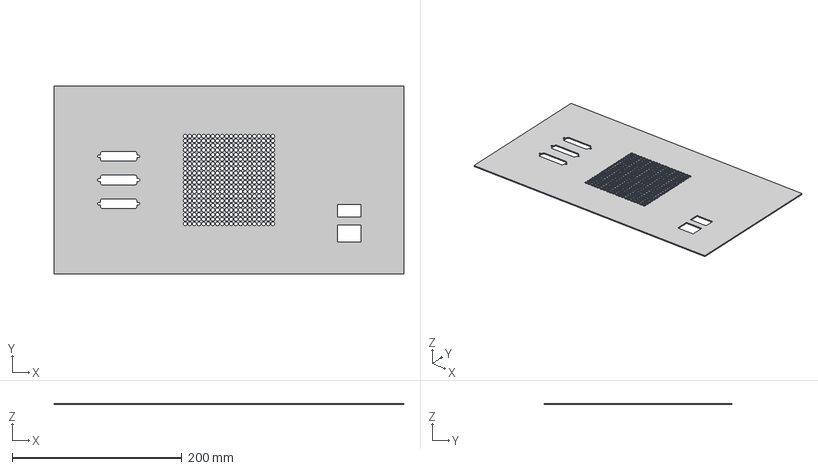
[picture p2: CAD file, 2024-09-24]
case/RearPanelV2.iges
412.8 x 222.2 x 1.59 mm

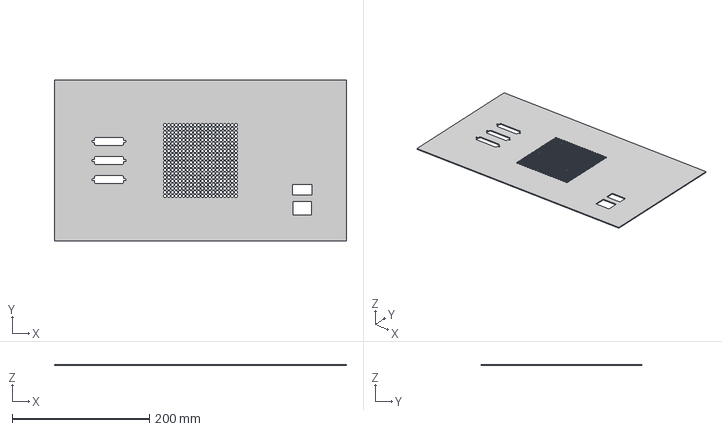
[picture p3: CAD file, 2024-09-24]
case/Bud Industries Case/RearPanel.iges
425.4 x 234.9 x 1.59 mm

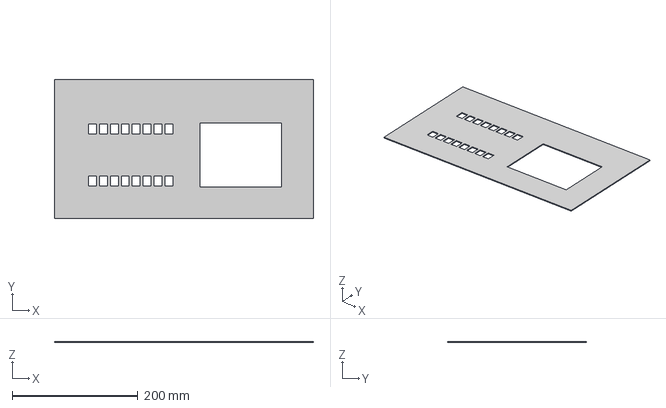
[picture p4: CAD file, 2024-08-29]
case/FrontPanel.iges
412.8 x 222.2 x 1.59 mm

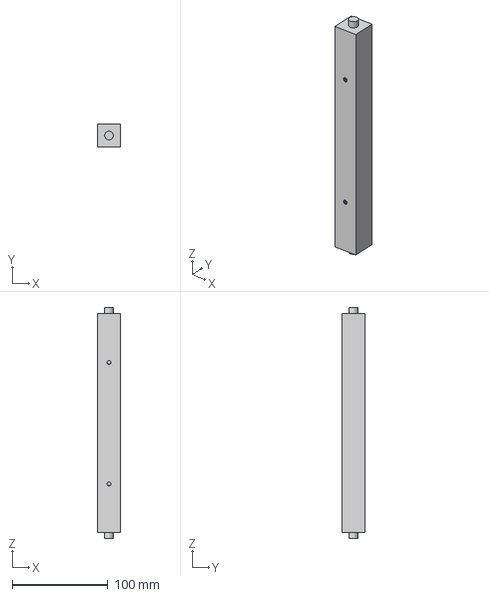
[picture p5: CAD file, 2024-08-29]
case/3D_Horizonal_Piece_9.iges
23.8 x 23.8 x 241.3 mm

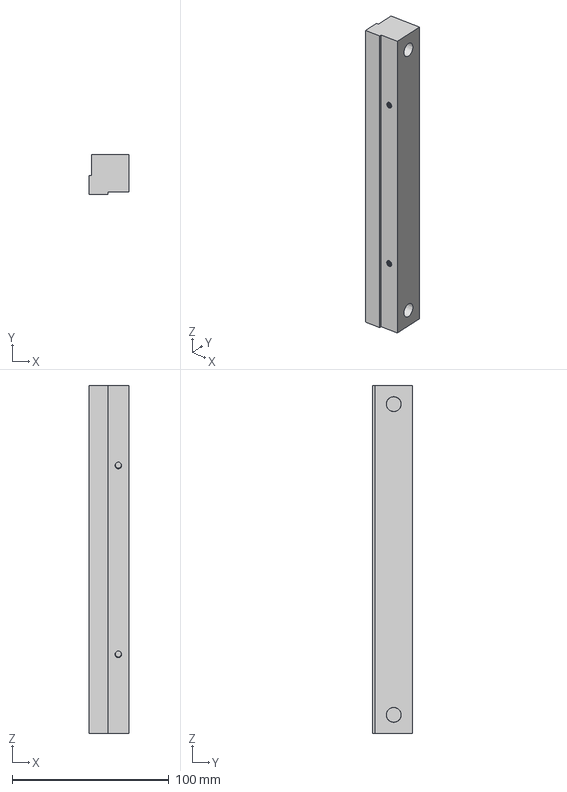
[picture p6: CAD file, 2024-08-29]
case/3D_Vertical_Piece.iges
25.4 x 25.4 x 222.2 mm

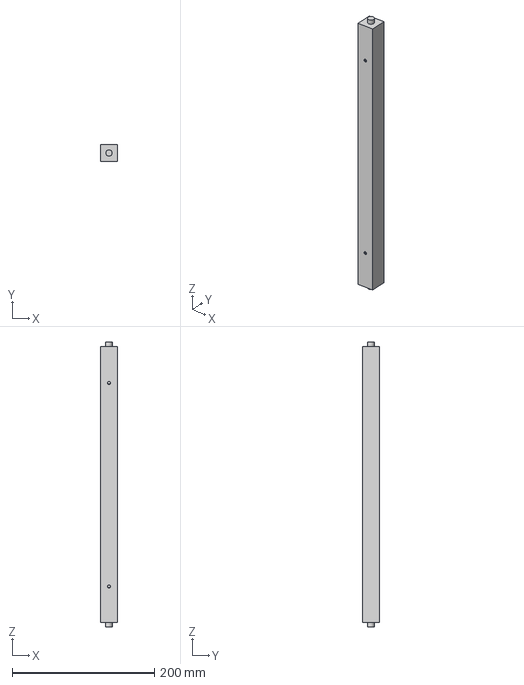
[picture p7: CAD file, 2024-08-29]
case/3D_Horizonal_Piece_15-1_4.iges
23.8 x 23.8 x 400.1 mm

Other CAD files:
case/RearPanelV1.iges

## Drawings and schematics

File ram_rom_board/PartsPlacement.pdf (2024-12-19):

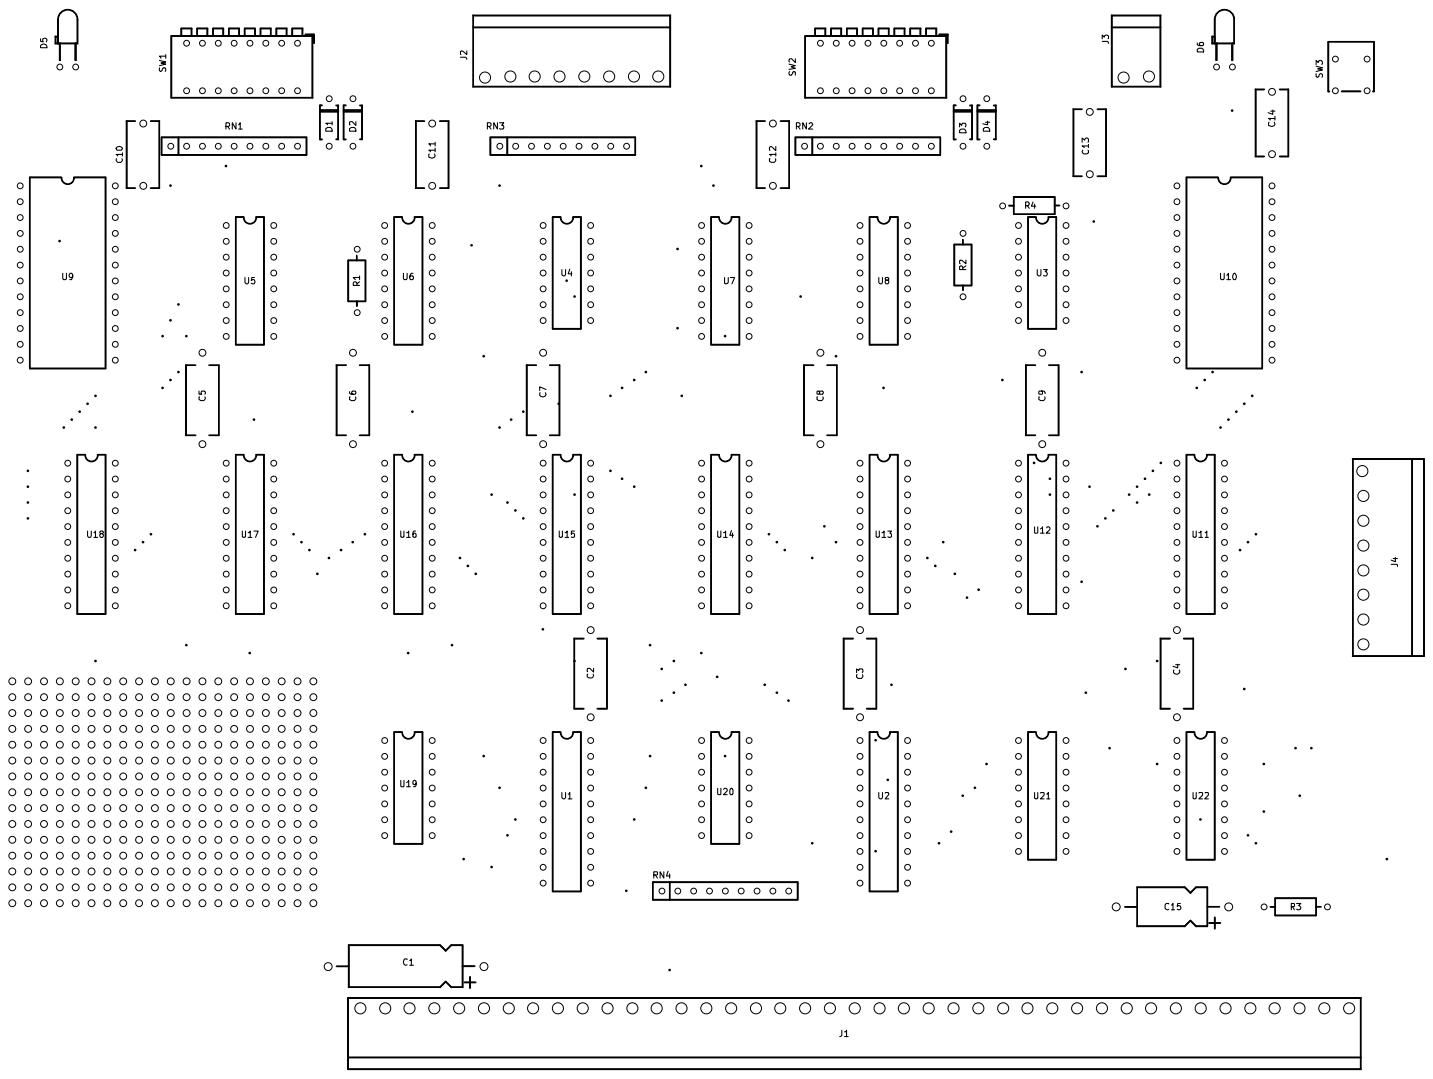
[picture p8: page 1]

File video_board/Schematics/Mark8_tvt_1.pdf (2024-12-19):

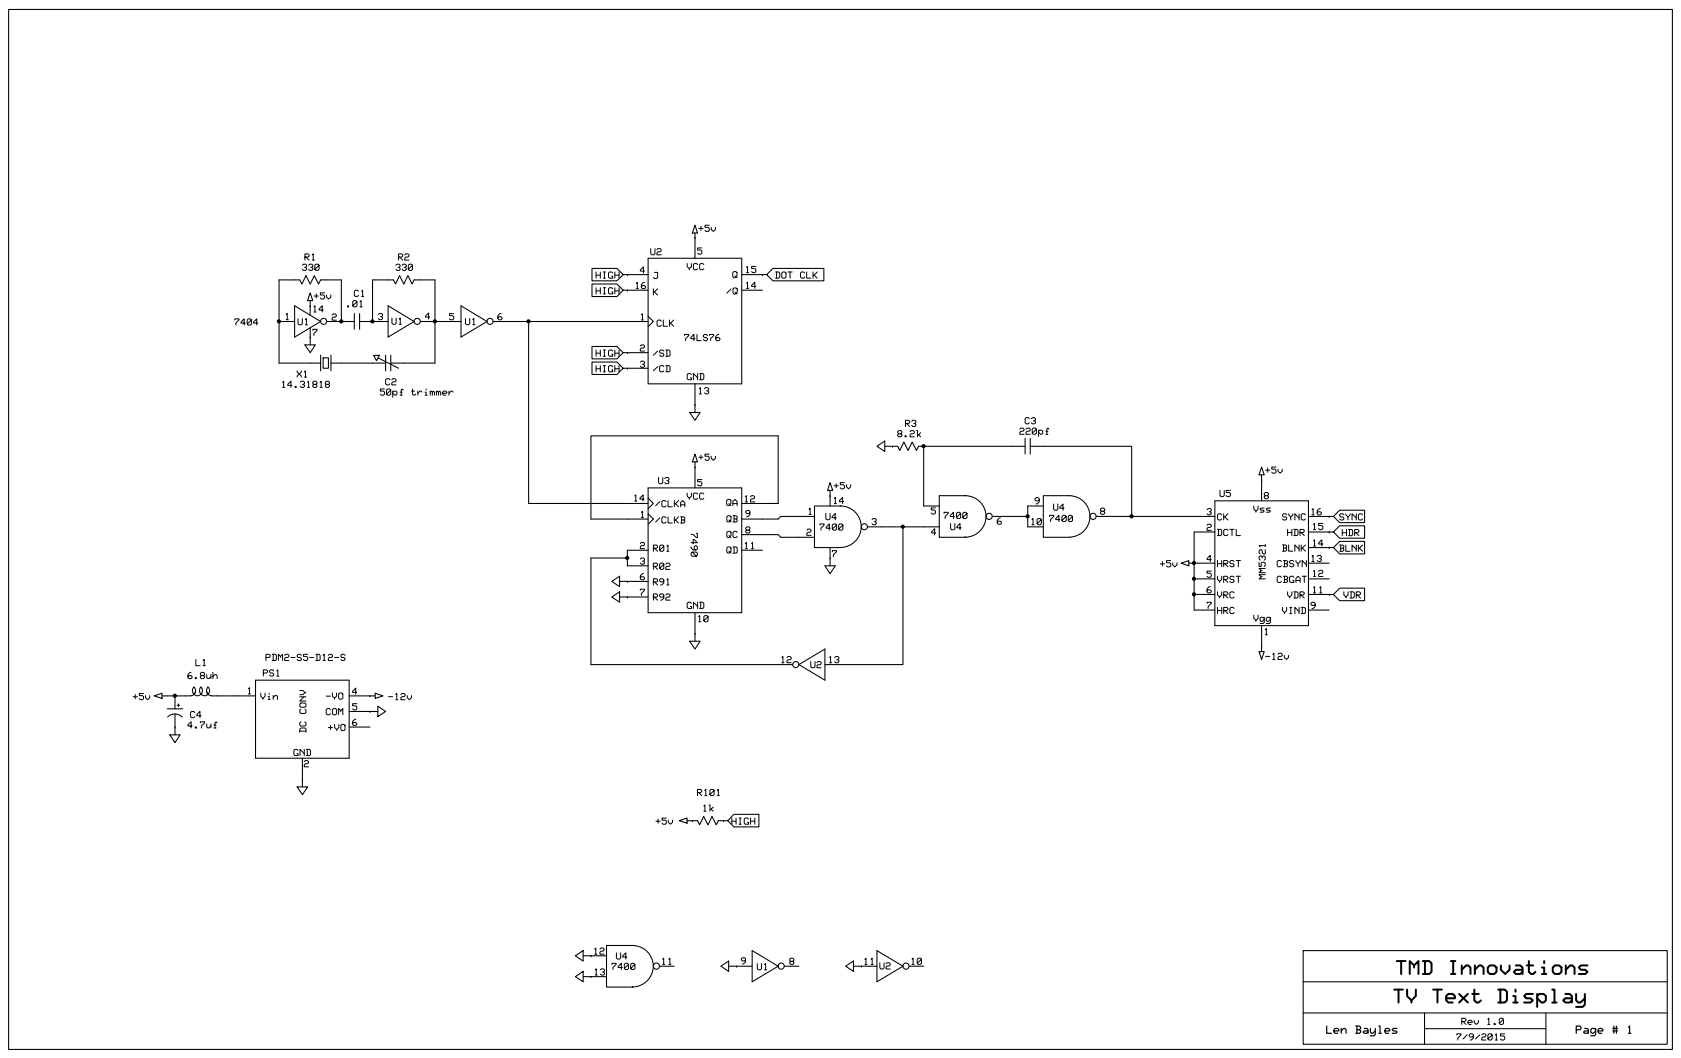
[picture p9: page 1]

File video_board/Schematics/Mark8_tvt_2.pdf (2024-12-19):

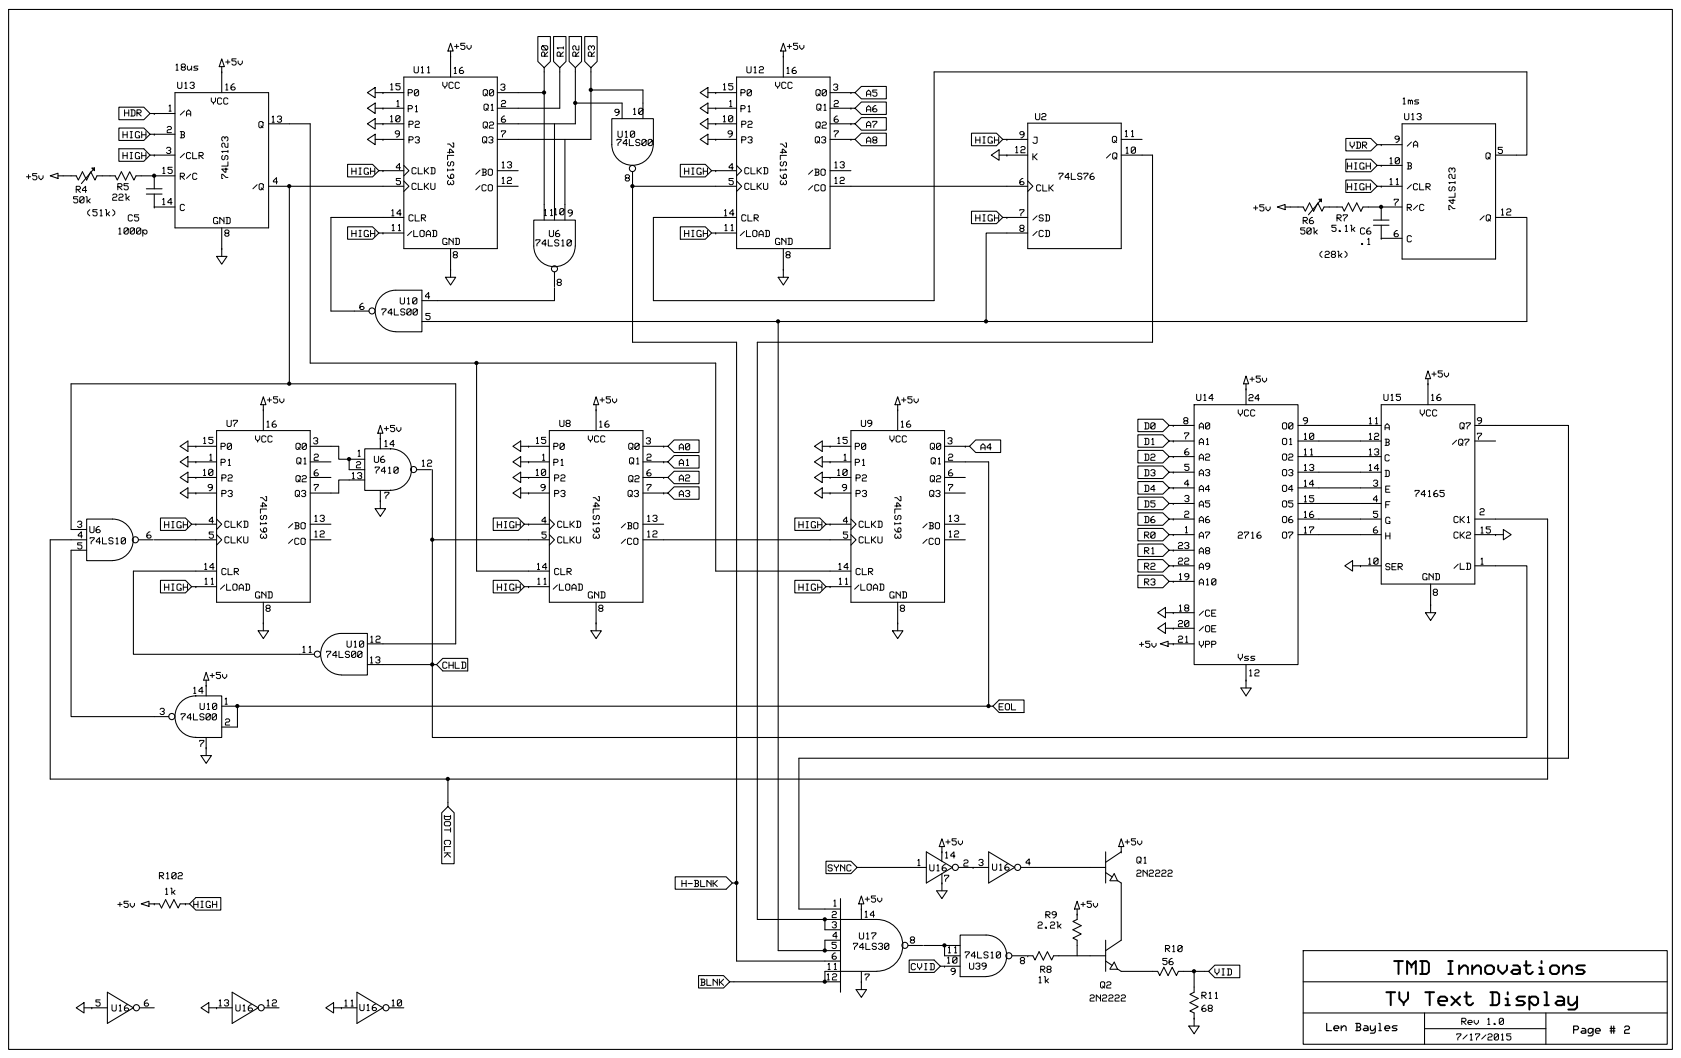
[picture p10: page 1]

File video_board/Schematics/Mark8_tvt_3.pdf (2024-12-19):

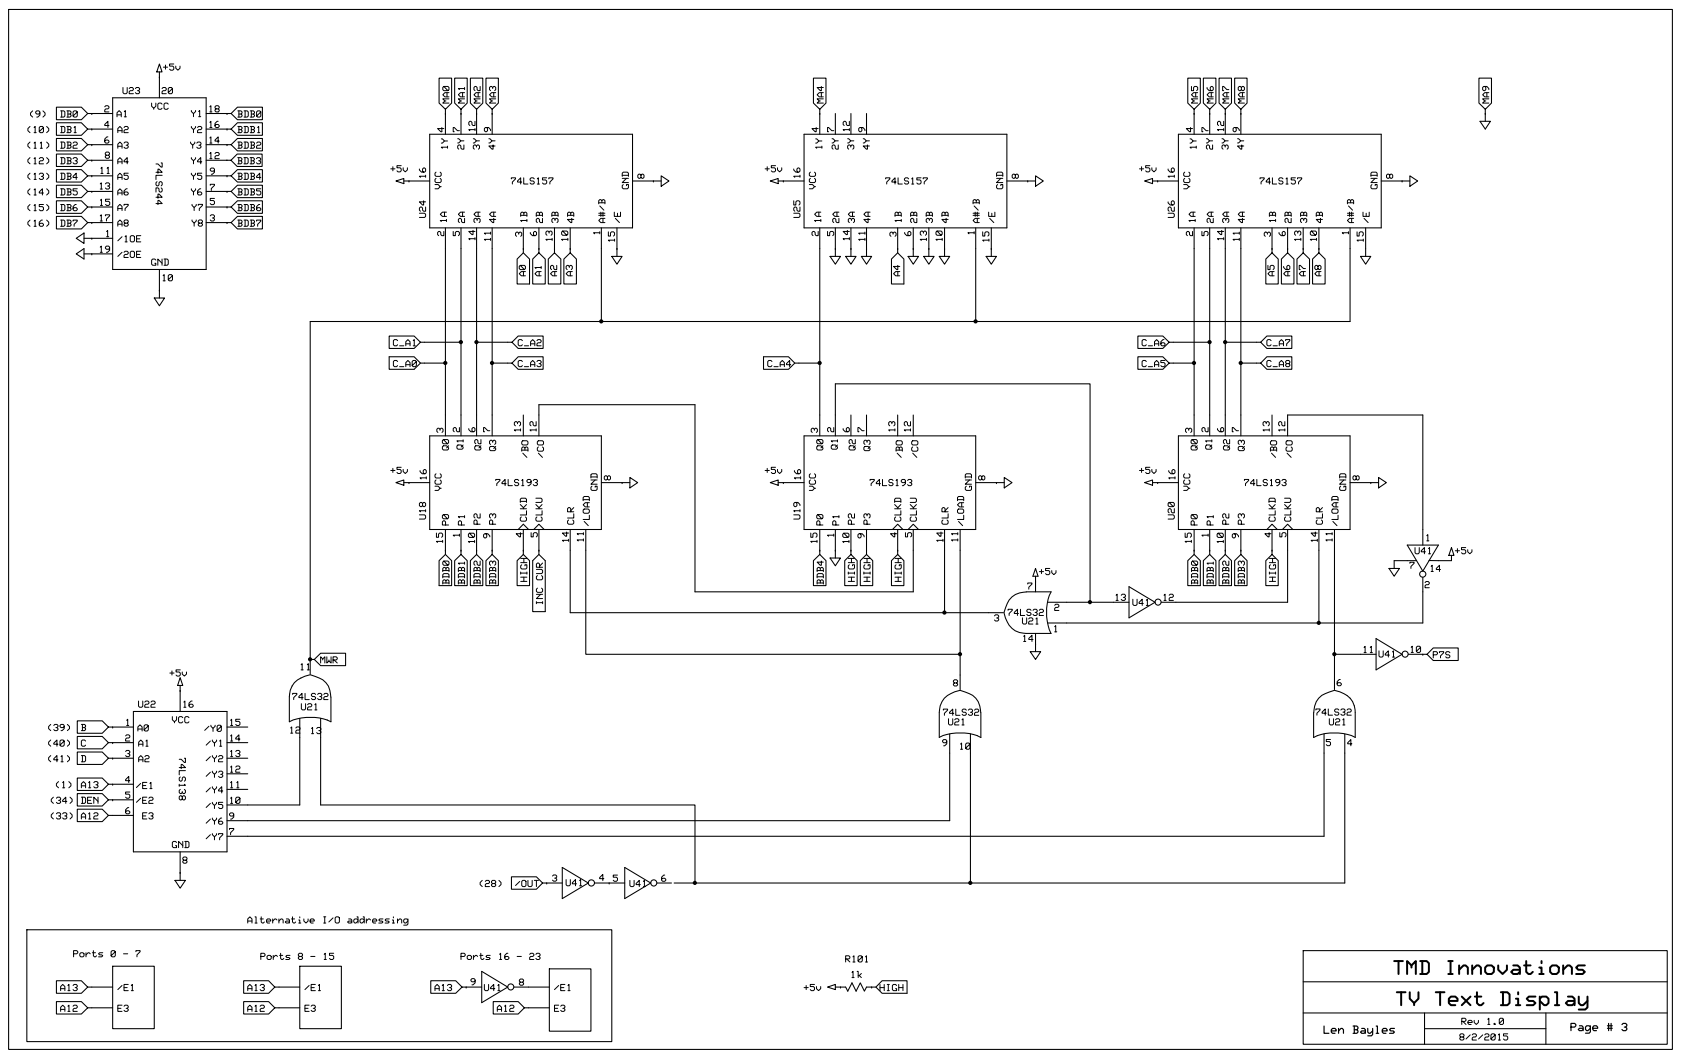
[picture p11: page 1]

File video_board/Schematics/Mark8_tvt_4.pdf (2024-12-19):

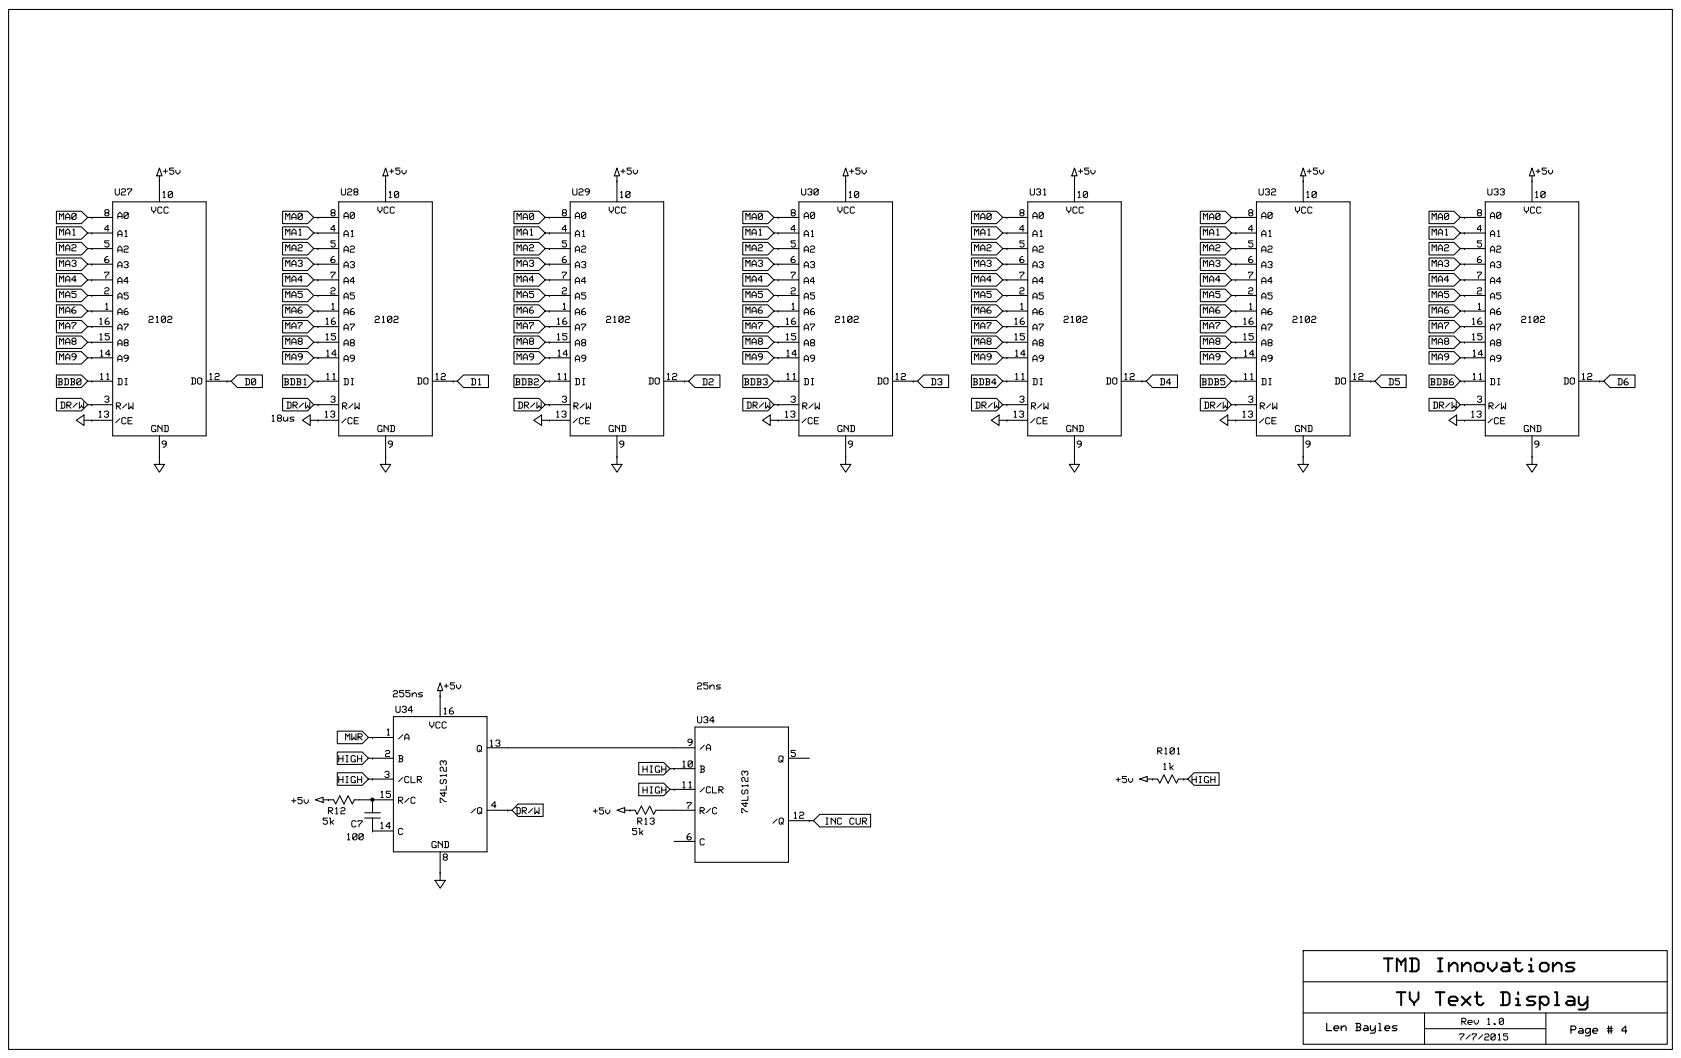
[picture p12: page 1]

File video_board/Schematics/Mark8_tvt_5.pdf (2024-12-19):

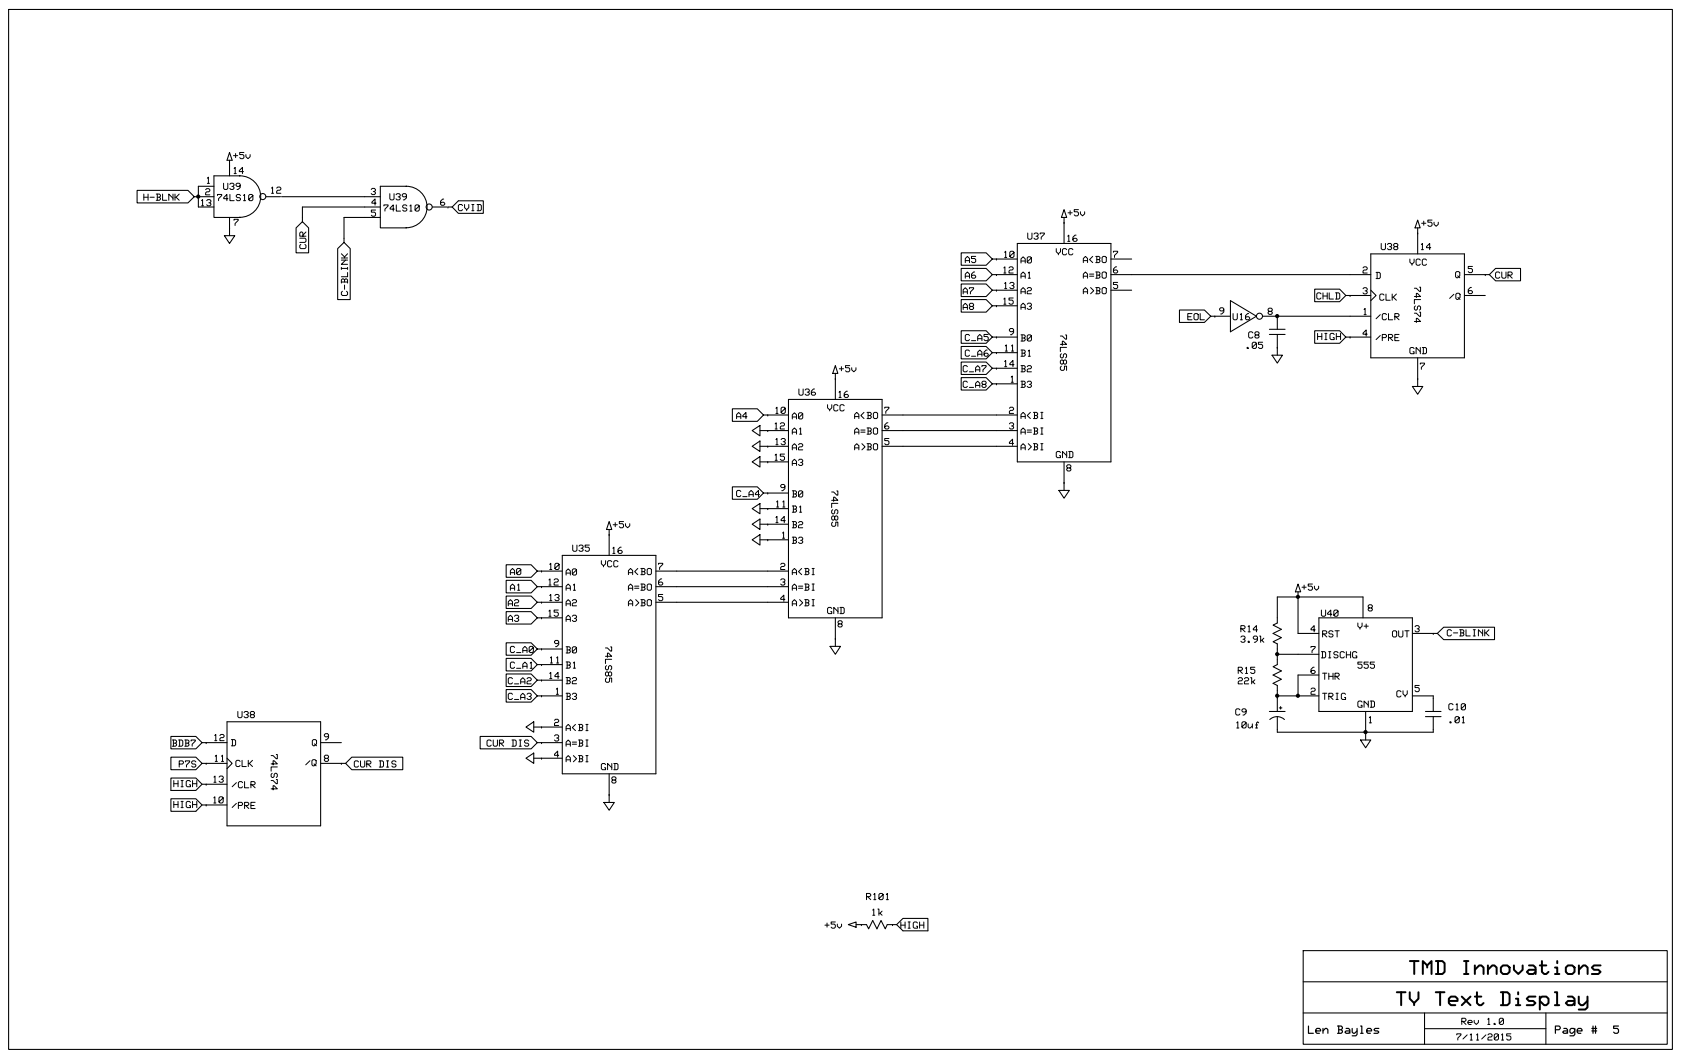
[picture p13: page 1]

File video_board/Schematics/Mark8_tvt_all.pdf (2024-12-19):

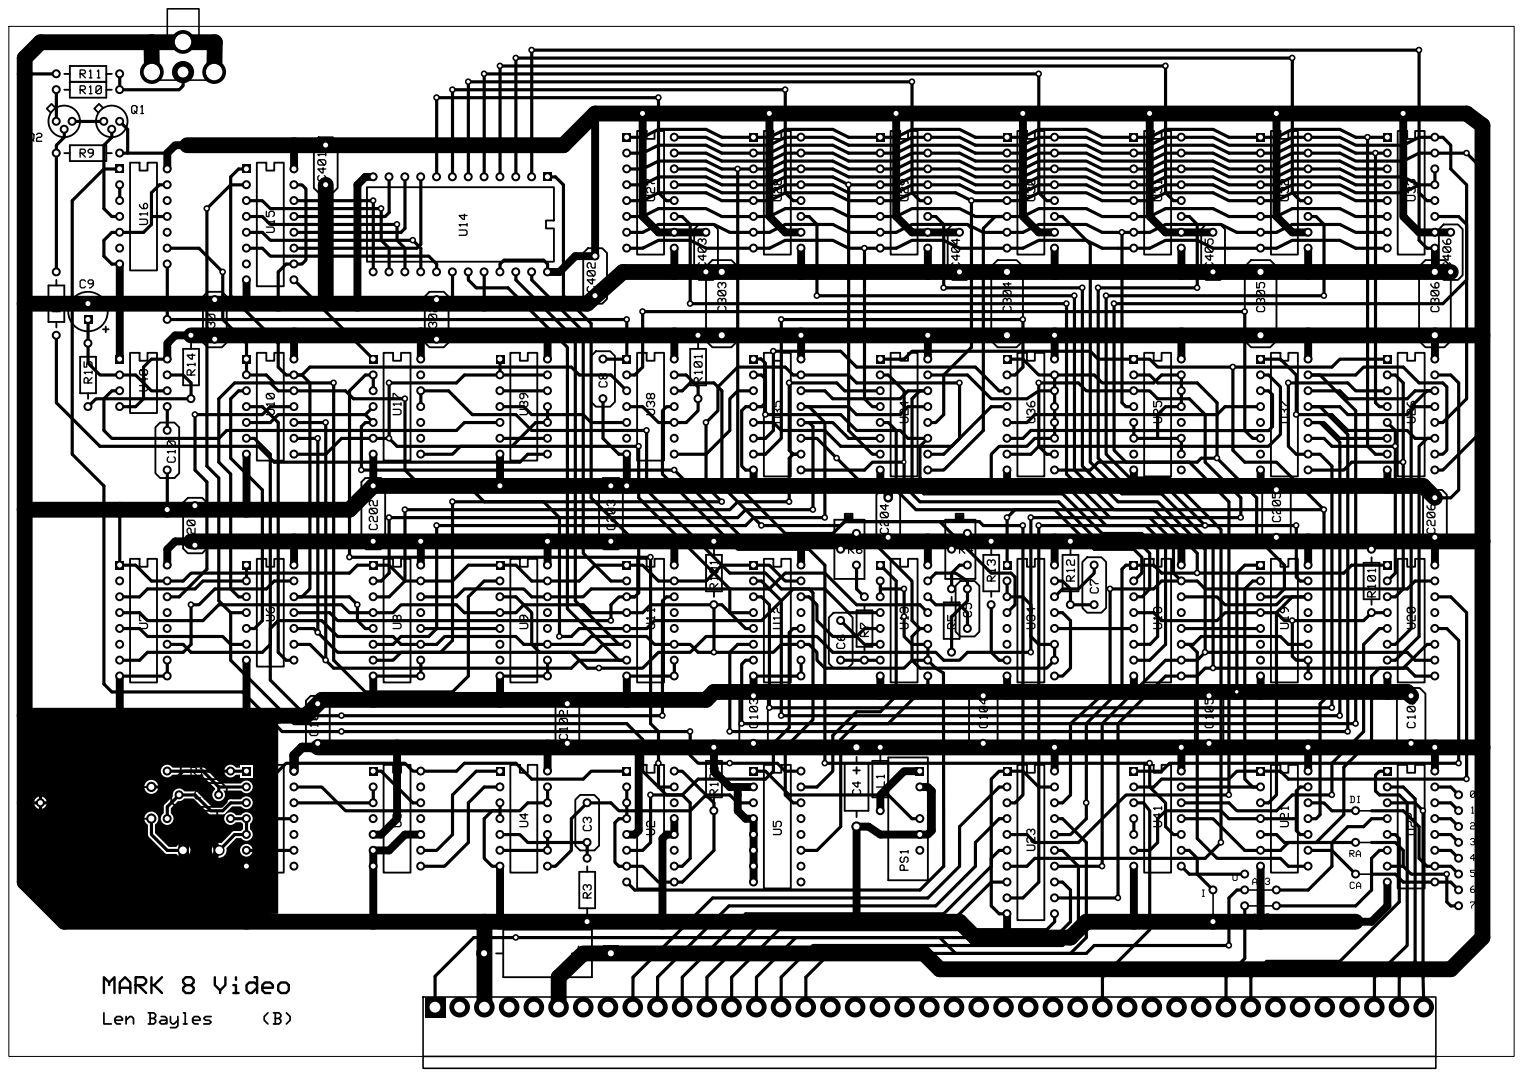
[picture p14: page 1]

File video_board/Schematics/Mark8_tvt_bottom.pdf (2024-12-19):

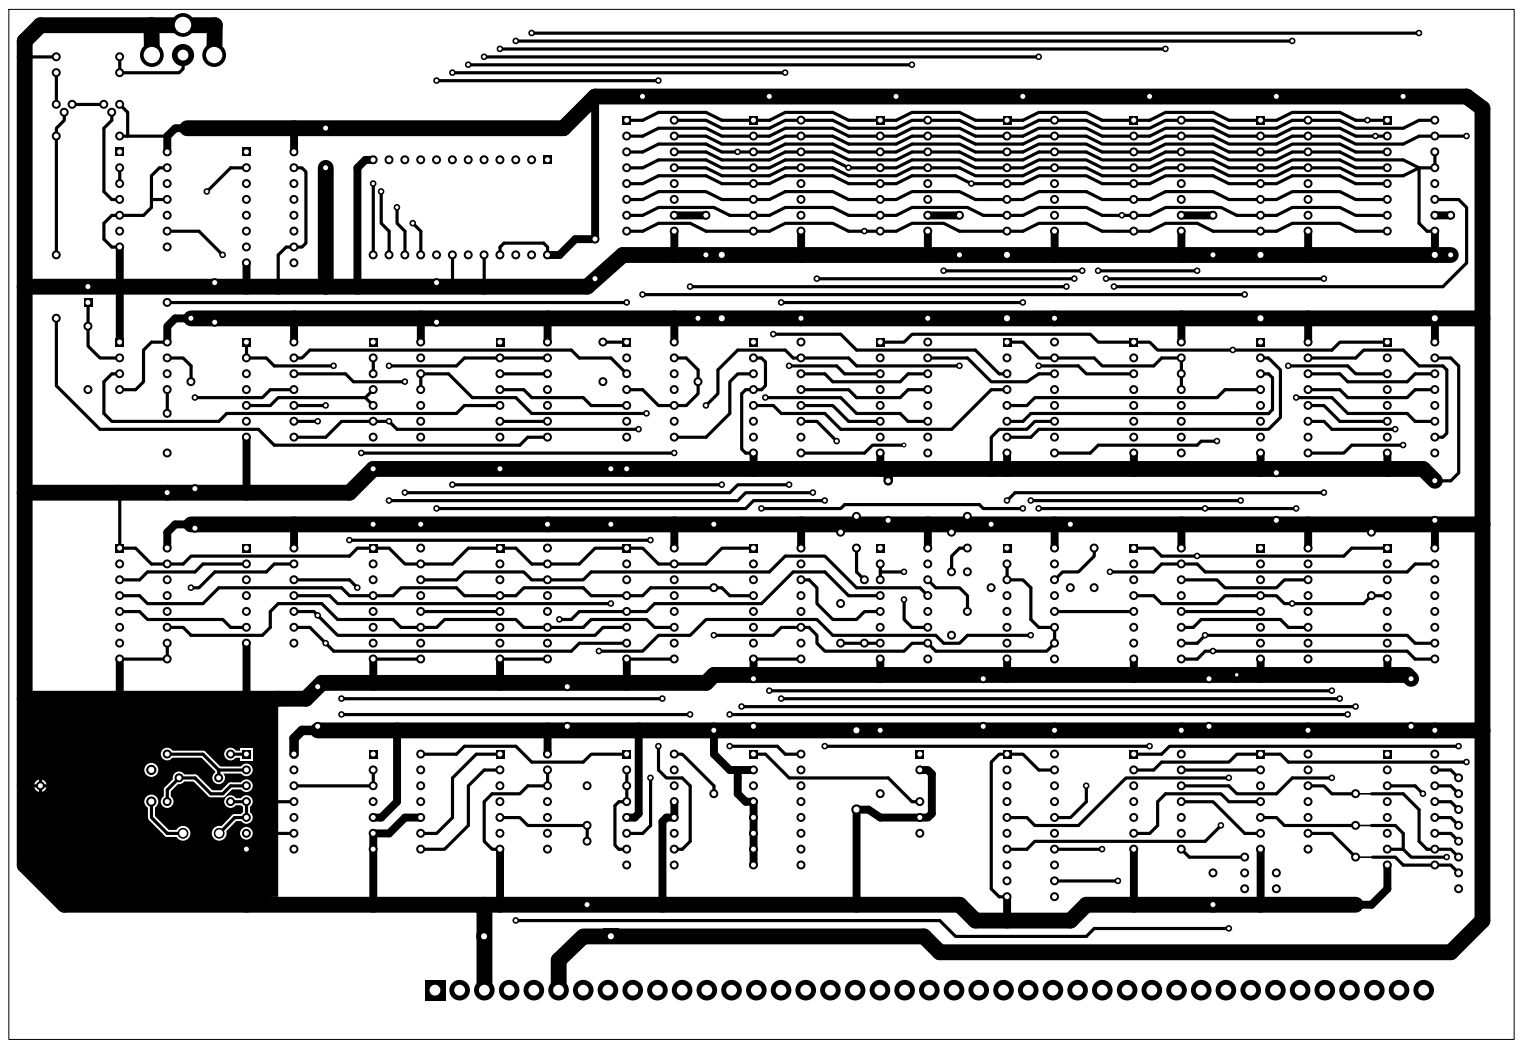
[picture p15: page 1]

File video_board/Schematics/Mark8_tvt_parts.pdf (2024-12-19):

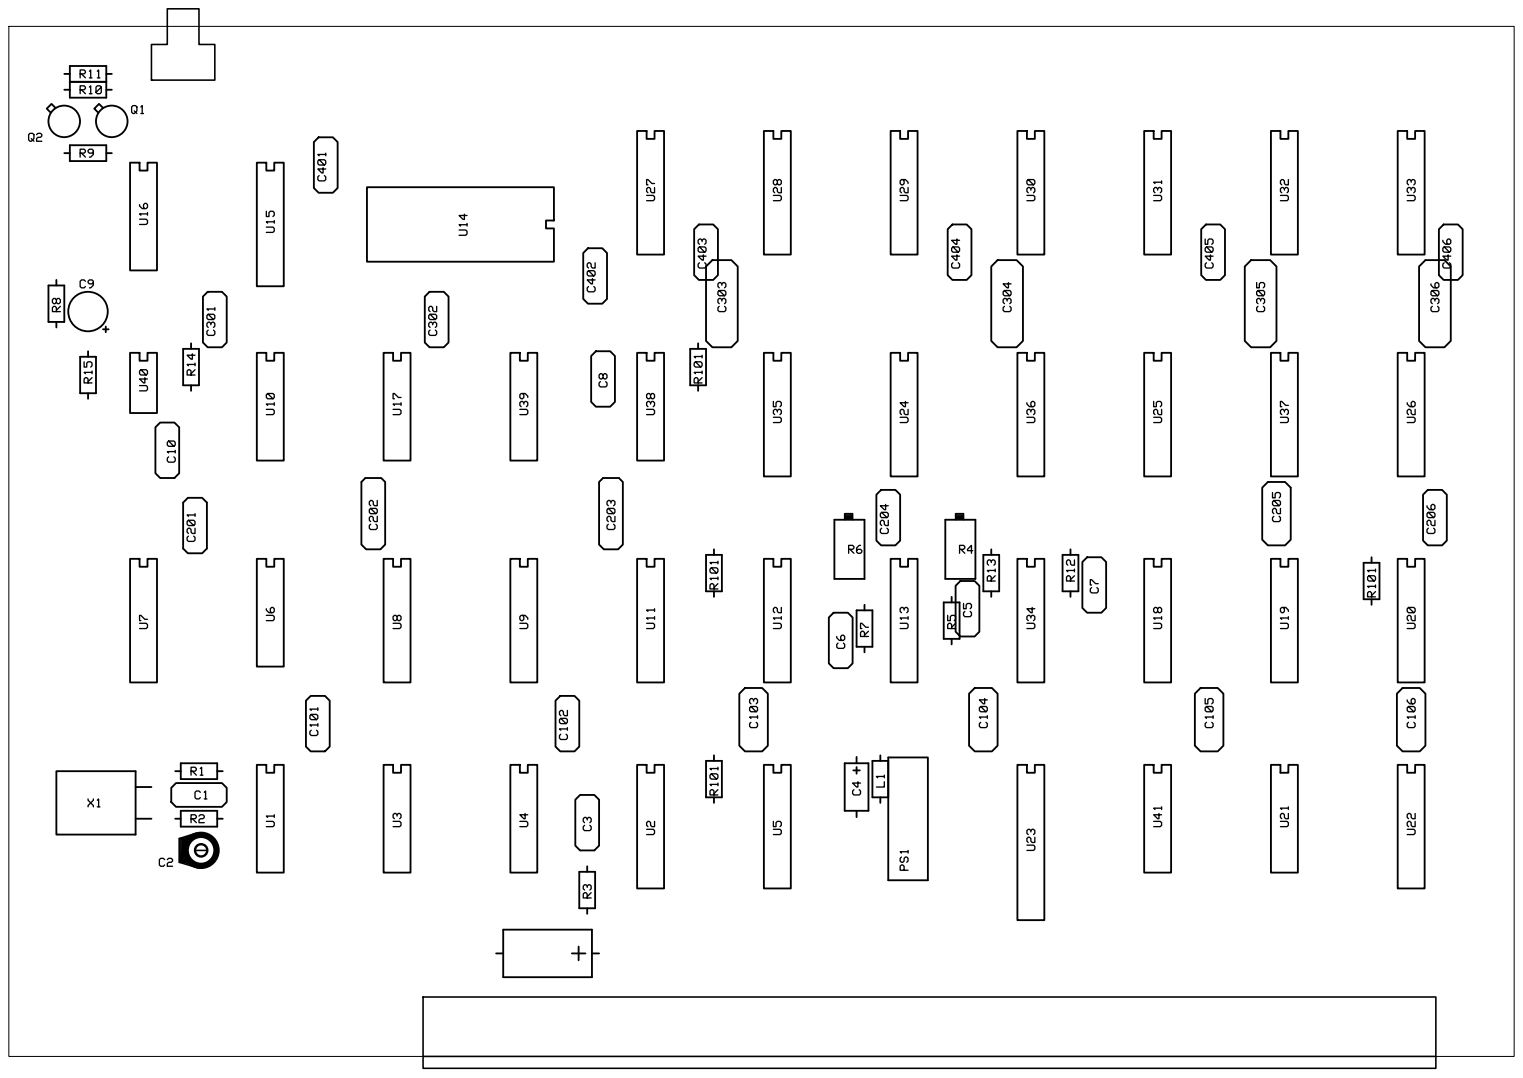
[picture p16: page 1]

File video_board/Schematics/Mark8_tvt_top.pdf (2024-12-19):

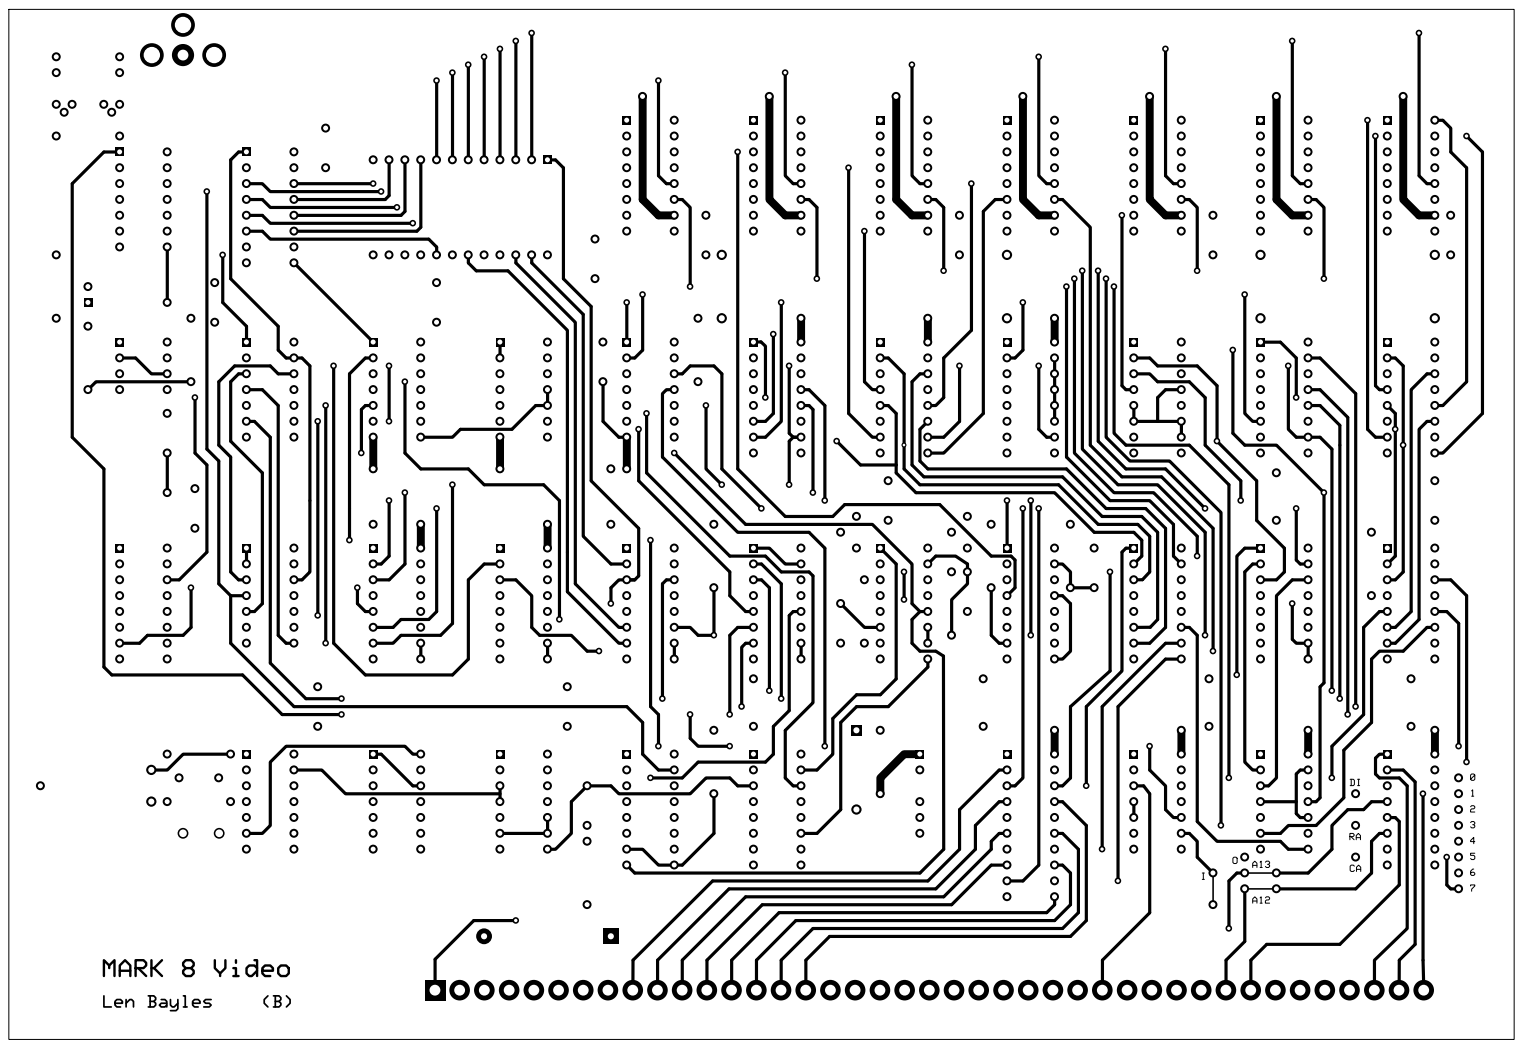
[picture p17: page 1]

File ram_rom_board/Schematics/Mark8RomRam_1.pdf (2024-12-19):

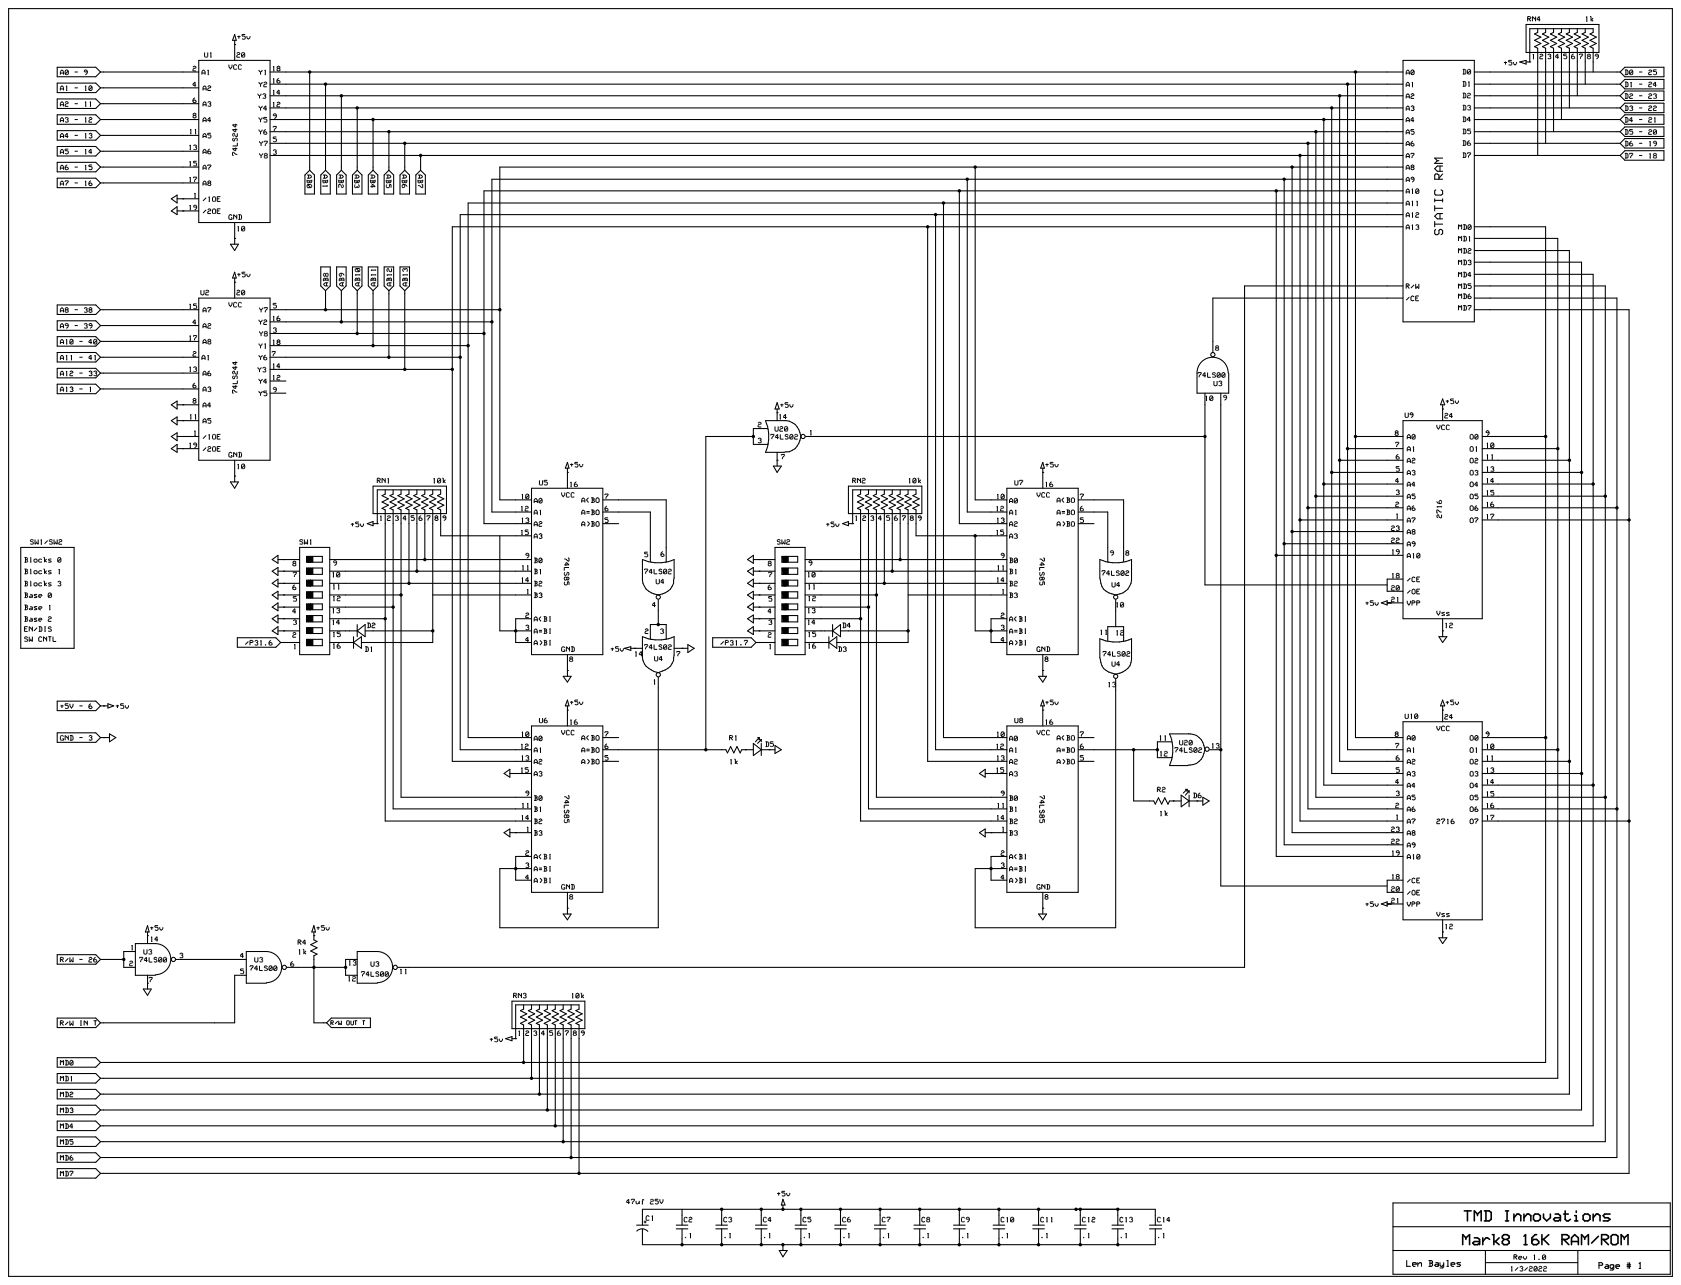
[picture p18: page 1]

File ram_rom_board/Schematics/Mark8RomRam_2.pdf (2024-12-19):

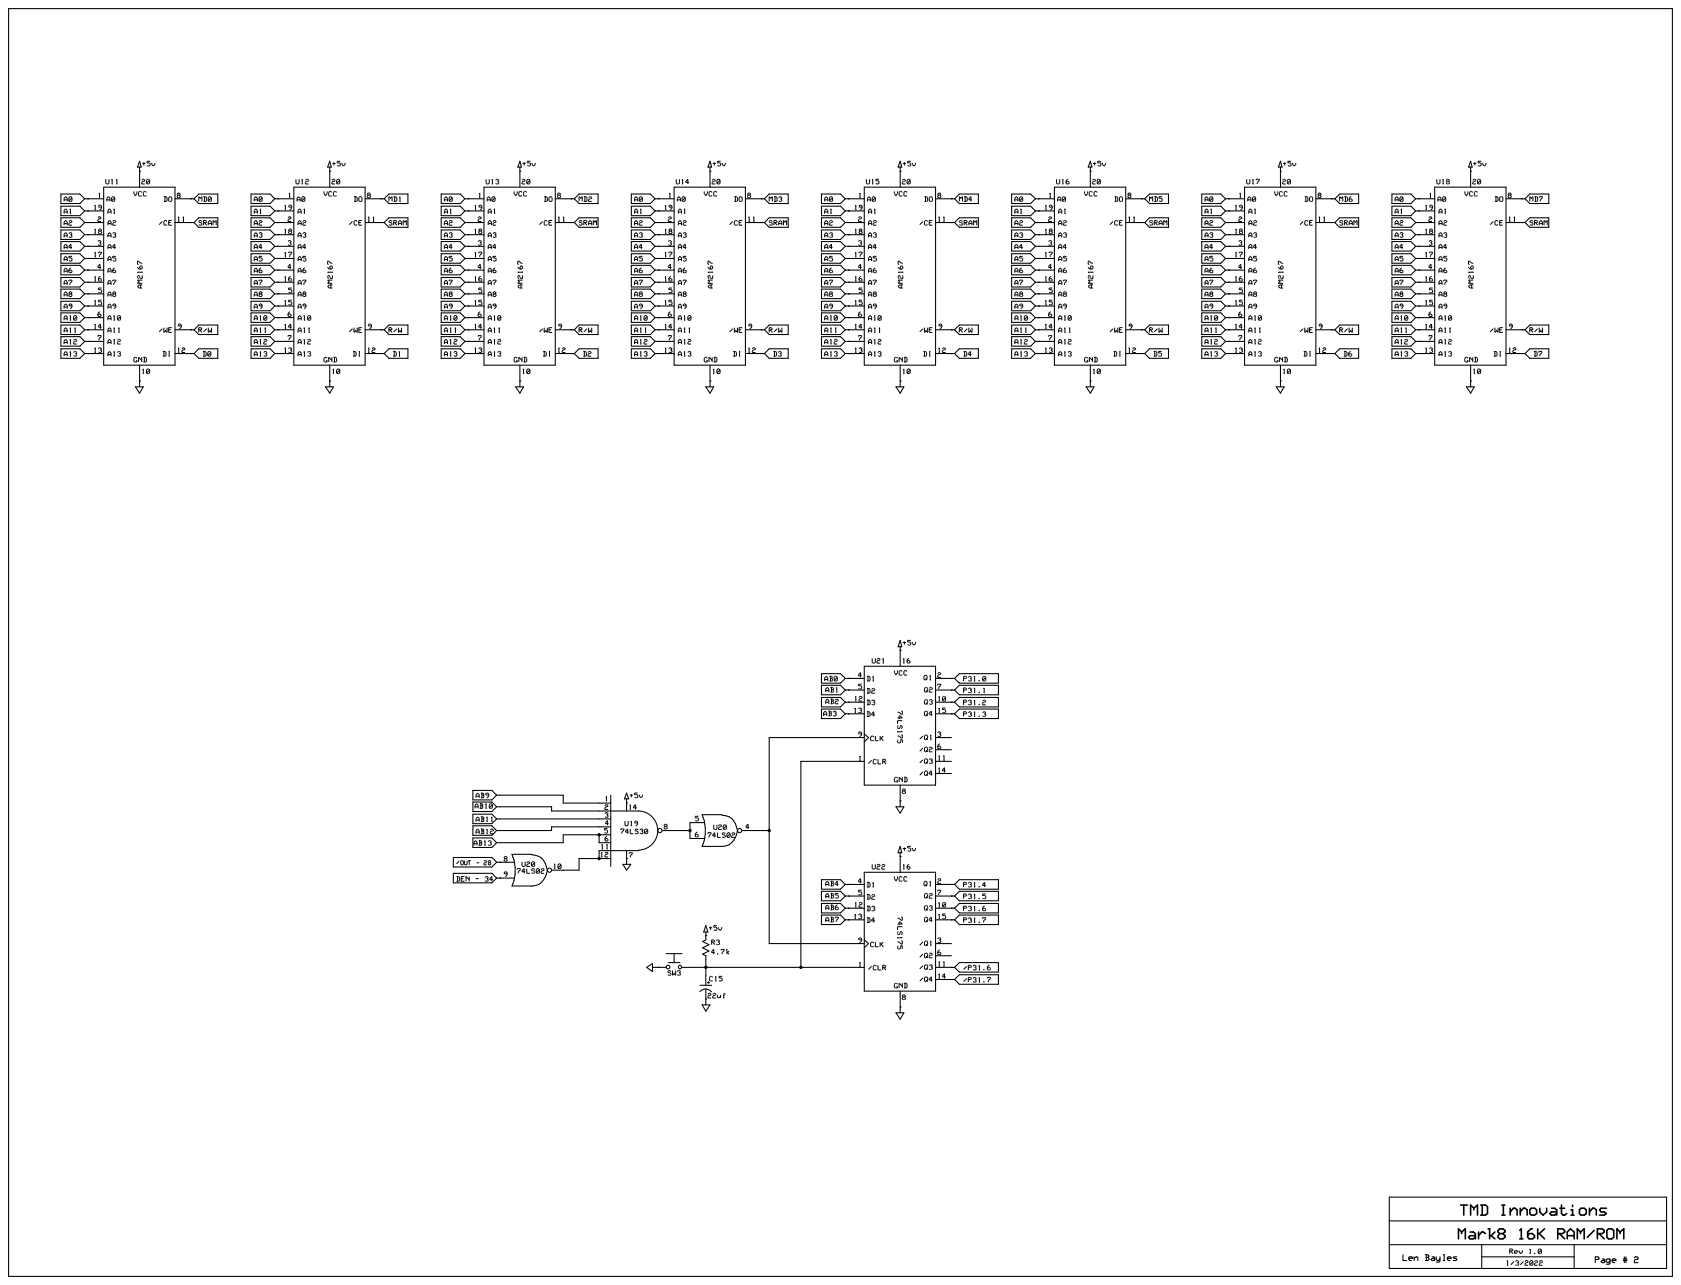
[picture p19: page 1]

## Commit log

2024-05-26 Adds information about the output ports board
2024-05-26 Adds links to connectors
2024-05-27 Updates 8-pin Molex link
2024-05-27 Updates Molex connector links
2024-06-05 Adds memory board
2024-06-18 Adds information about address latch board
2024-07-02 Adds details about Input Multiplex Board
2024-07-04 Adds info about CPU board
2024-08-13 Adds info about the power supply
2024-08-13 PCB URL
2024-08-13 PSU schematic and gerber
2024-08-13 Heat sink wording
2024-08-29 Adds info about the case
2024-08-29 Adds case CAD files
    [2D_Sheetmetal_Fan_Grill.step, 3D_Horizonal_Piece_15-1_4.iges, 3D_Horizonal_Piece_9.iges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]
2024-08-29 Updates CAD files
    [2D_Sheetmetal_Fan_Grill.iges, 2D_Sheetmetal_Fan_Grill.step, Cutout_Sheet_Rev_1.iges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]
2024-08-30 Adds case parts list
2024-09-24 Adds CAD files
    [FrontPanel.iges, RearPanel.iges, RearPanelV1.iges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]
2024-10-29 Adds original case info
2024-11-01 Adds 8008 assembler and keyboard echo software
2024-11-01 Adds additional instructions to assembler
2024-11-22 Adds Gerbers
2024-11-22 Adds message about Gerbers
2024-12-19 Adds details about Len Bayles RAM/ROM board.
2024-12-19 Adds RAM/ROM board schematics and gerber
2024-12-19 Adds info about video board
    [Mark8_tvt_BOM.xlsx]
2024-12-19 Adds charGen.hex
2025-02-17 Video board configuration
2025-03-04 Adds PCB info
